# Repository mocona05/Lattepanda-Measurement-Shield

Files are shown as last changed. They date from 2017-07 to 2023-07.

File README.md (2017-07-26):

# Lattepanda-Measurement-Shield



Lattepanda Measurement Shield















https://tk-labs.blogspot.kr/2017/04/lattepanda-single-board-pc-mersument.html

https://youtu.be/Gao8uBBO_YQ?list=UUIPe5kHdhJTlKDBbaLlJSWA

https://tk-labs.blogspot.kr/2017/07/lattepanda-shield-4-wire-kelvin-circuit.html

https://youtu.be/S4dbSf8vbH0?list=UUIPe5kHdhJTlKDBbaLlJSWA

https://youtu.be/iEvZpjPi1Qs?list=UUIPe5kHdhJTlKDBbaLlJSWA

https://youtu.be/Fq8yy6oz41c?list=UUIPe5kHdhJTlKDBbaLlJSWA

https://tk-labs.blogspot.kr/2017/07/lattepanda-shiled-thermocouple-k-type.html

https://youtu.be/_V4gtJXVWEc

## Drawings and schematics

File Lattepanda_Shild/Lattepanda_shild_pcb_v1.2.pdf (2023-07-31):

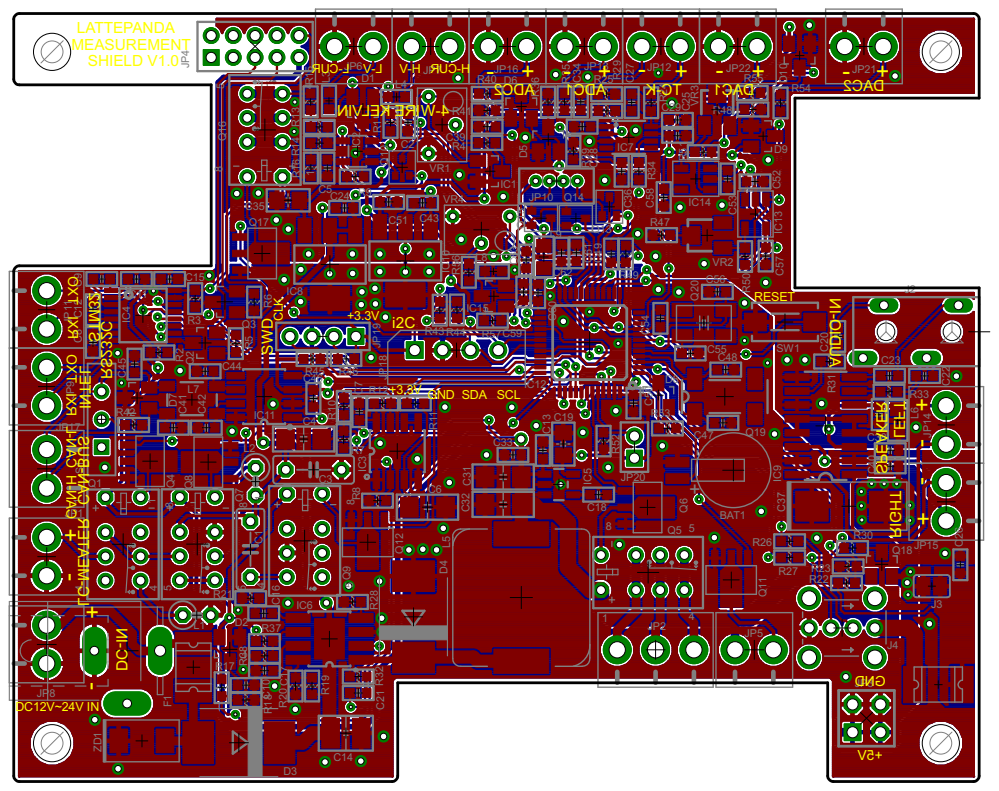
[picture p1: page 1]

T2XO RXI INTEL RXI TXO CAN-BUS

JP1 | C18 BAT1

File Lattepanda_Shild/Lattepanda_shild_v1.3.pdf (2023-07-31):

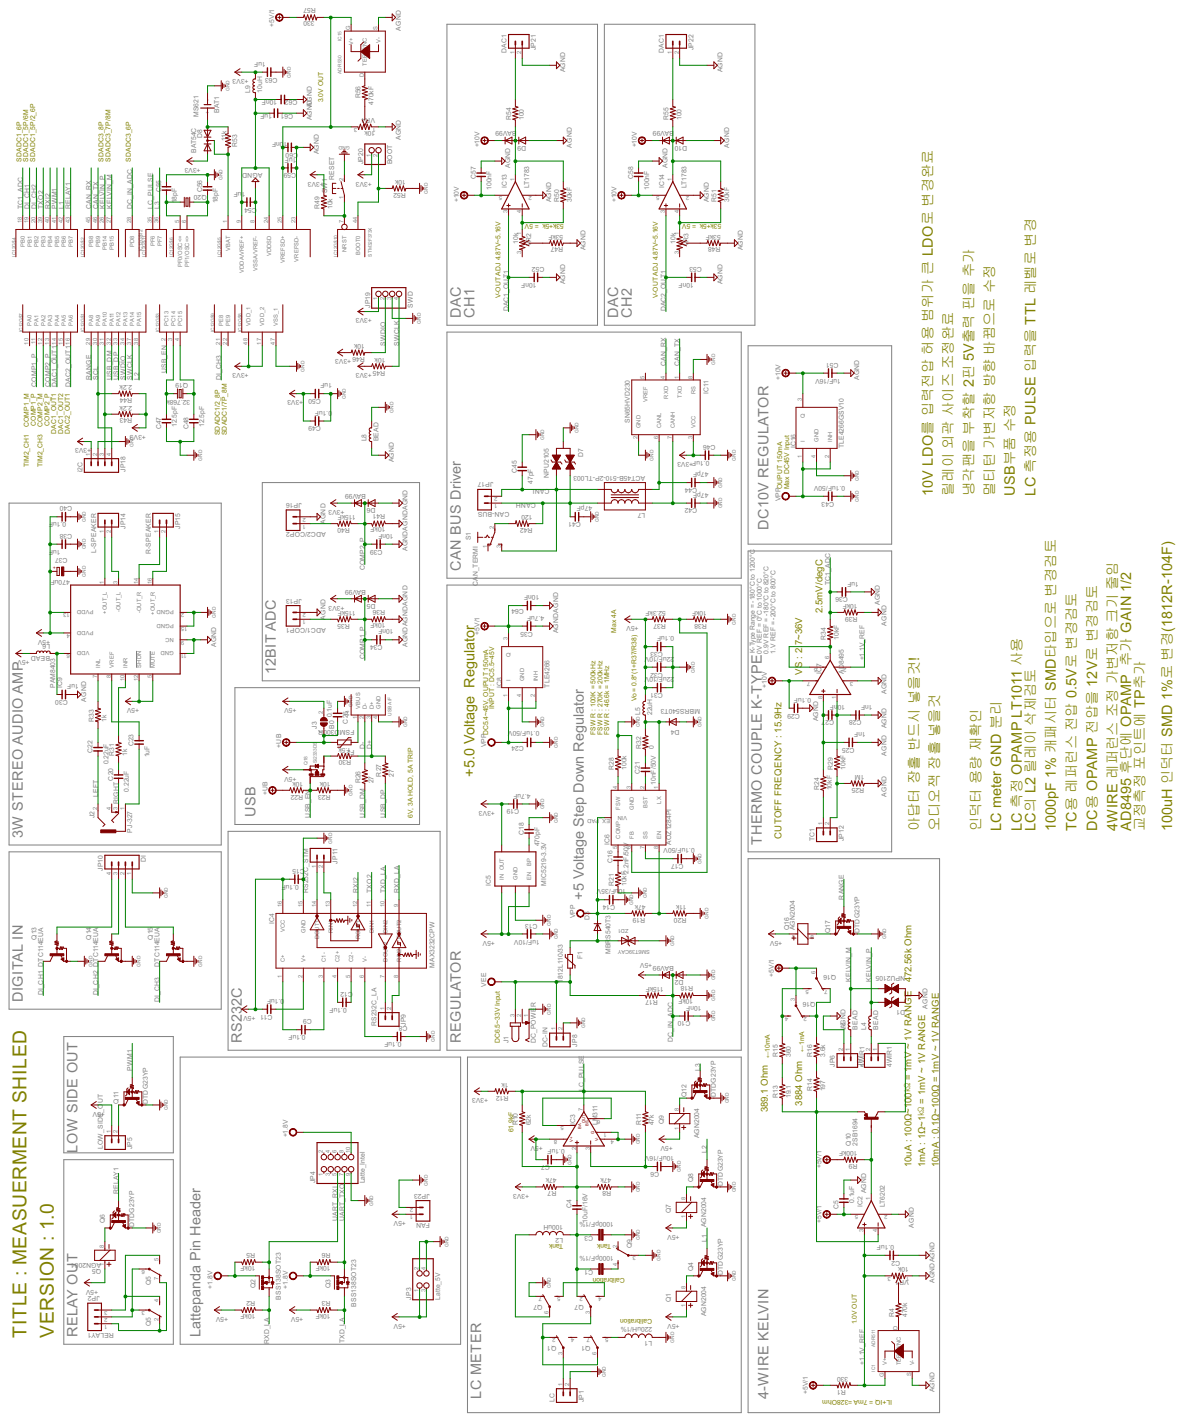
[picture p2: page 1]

1 VSSA/VREF- 8 VDDA/VREF+

LC 측정용 PULSE 입력을 TTL 레벨로 변경

10V LDO를 입력전압 허용 범위가

가 GAIN 1/2 교정측정 포인트에 TP추

TC용 레퍼런스 전압 0.5V로 변경검토

+5 Voltage Step Down Regulator

LC meter GND 분리

Lattepanda Pin Header USB

LOW SIDE OUT RELAY OUT DIGITAL IN

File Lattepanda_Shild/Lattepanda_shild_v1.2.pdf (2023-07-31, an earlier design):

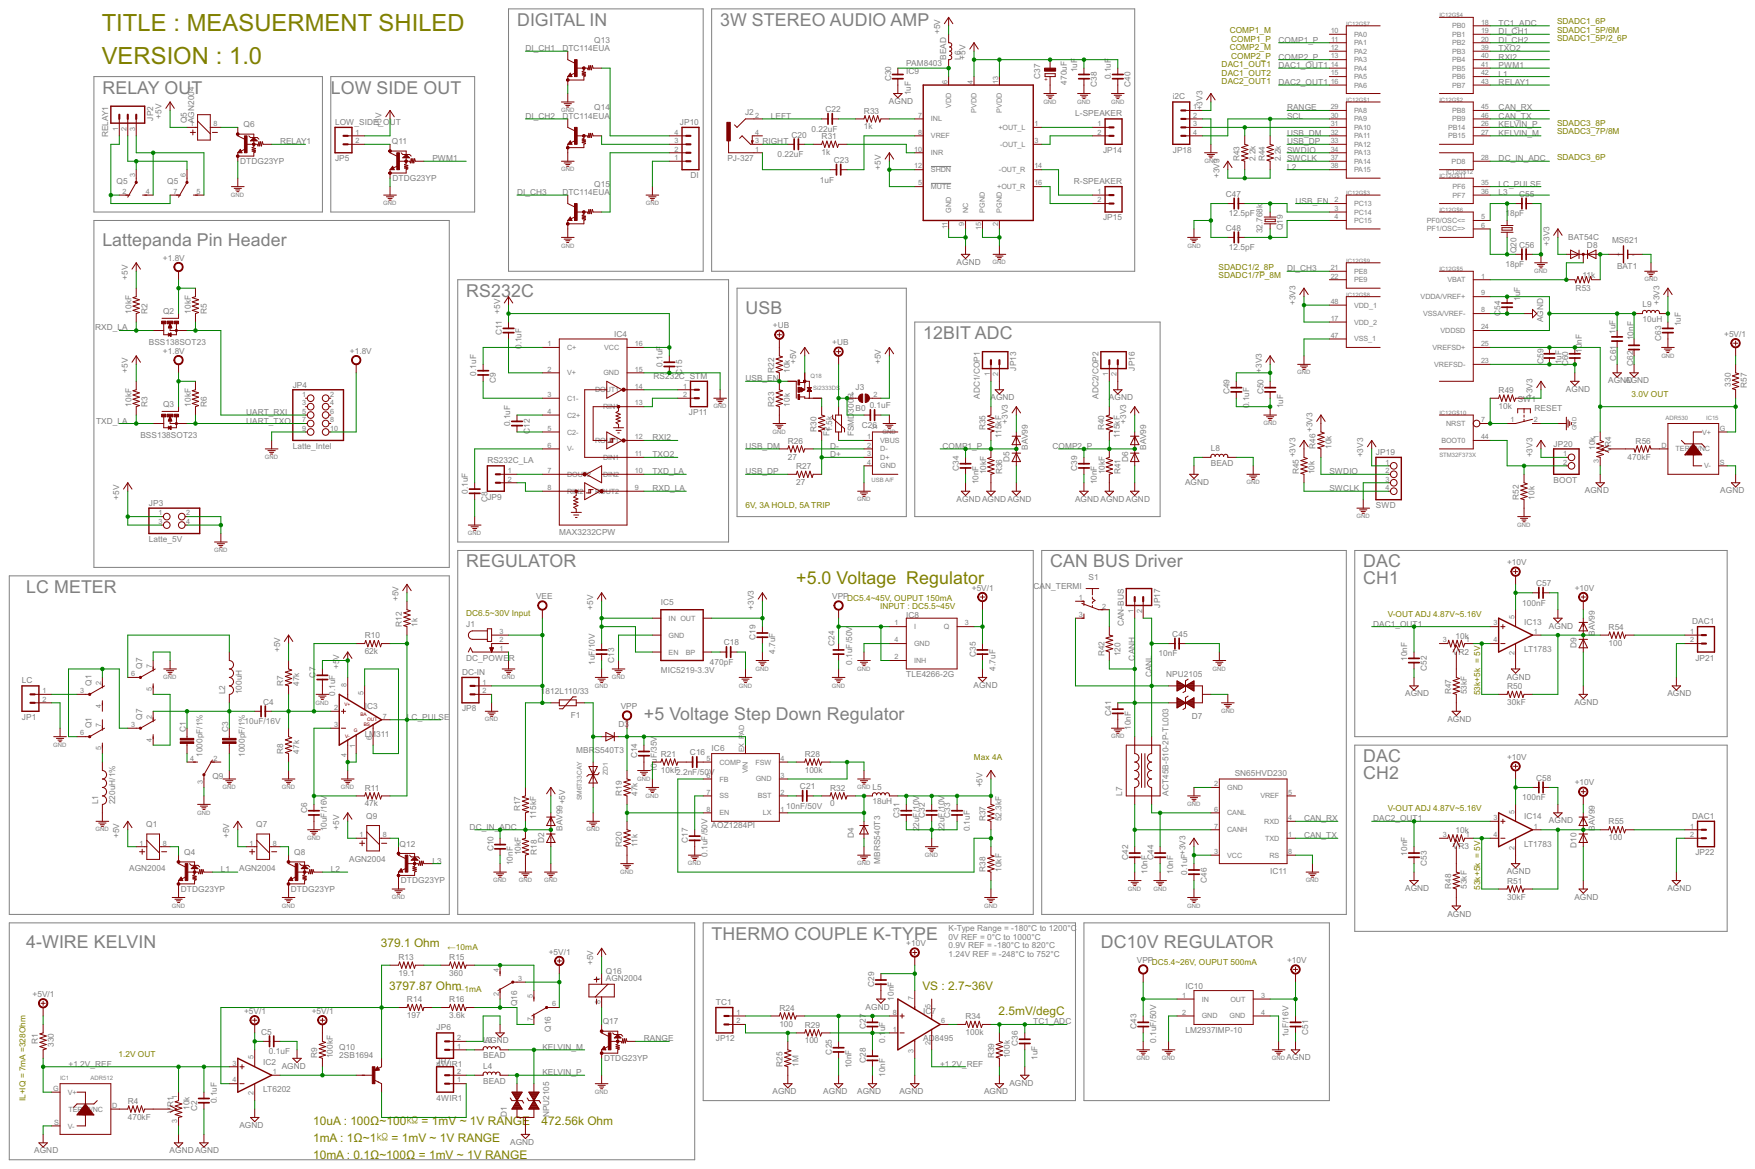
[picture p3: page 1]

+5 Voltage Step Down Regulator

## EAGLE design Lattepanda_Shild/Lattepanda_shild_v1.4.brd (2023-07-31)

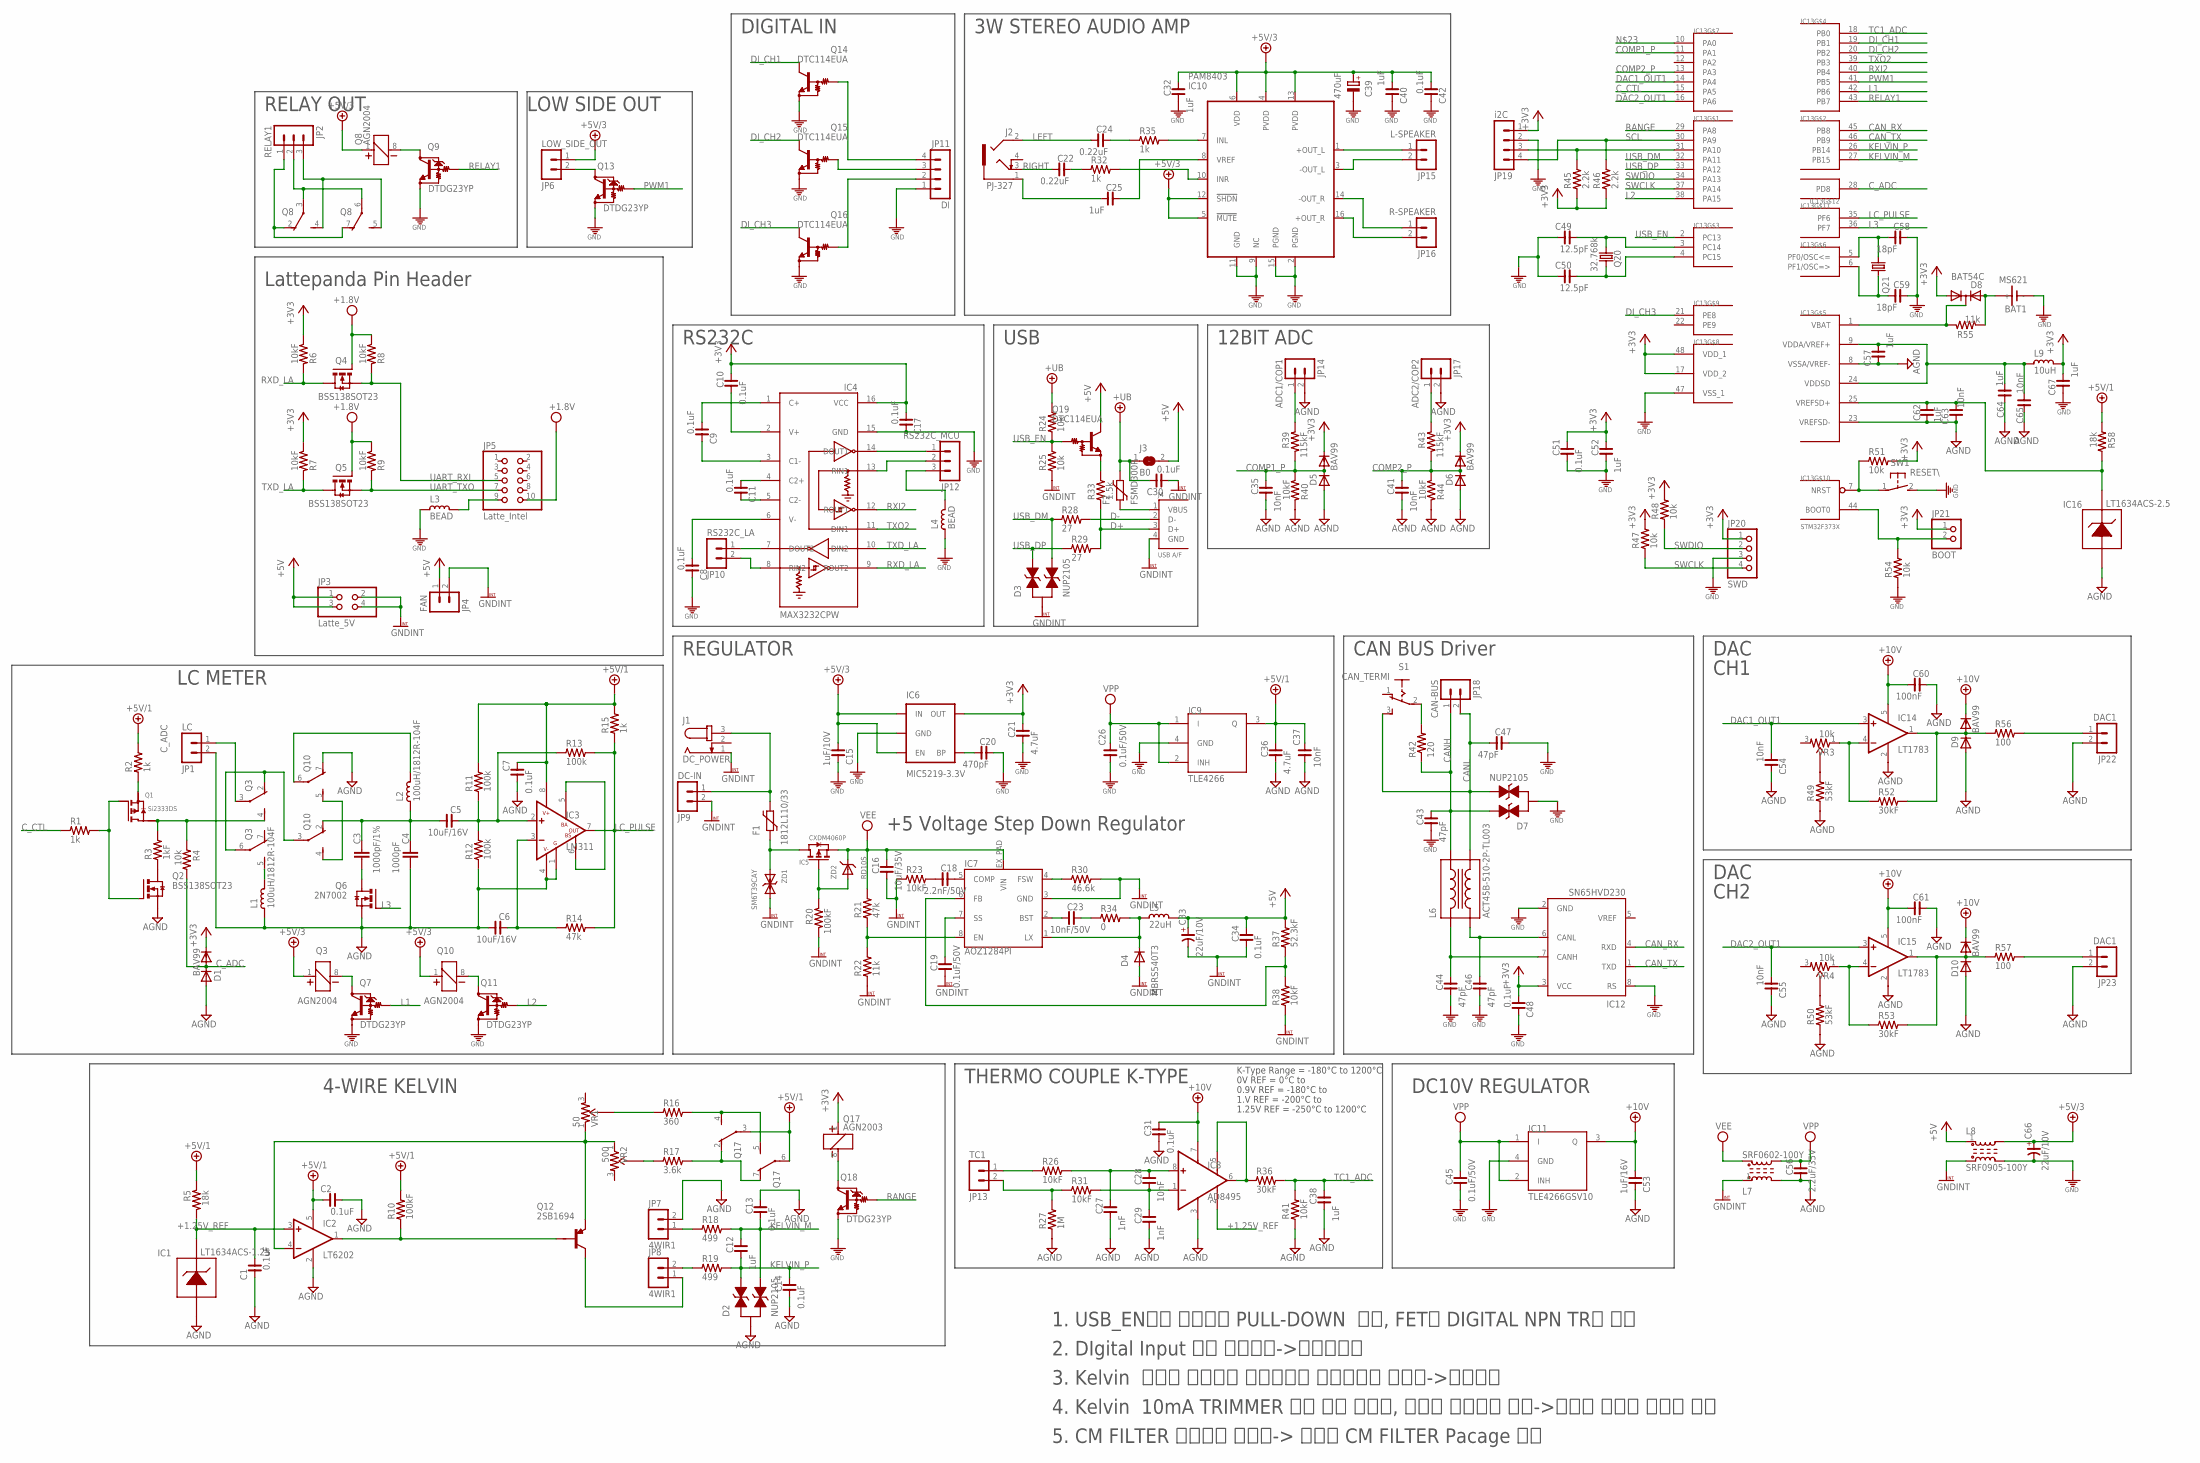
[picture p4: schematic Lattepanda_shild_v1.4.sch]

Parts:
BAT1: MS621
C1, C2, C7, C8, C9, C10, C11, C13, C14, C17, C30, C31, C34, C42, C48, C51: 0.1uF; C0603
C3: 1000pF/1%; C050-025X075
C4: 1000pF; C050-025X075
C5, C6: 10uF/16V; C3216
C12, C25, C32, C38, C40, C52, C57, C62, C64, C67: 1uF; C0603
C15: 1uF/10V; C0603
C16: 10uF/35V; C3225
C18: 2.2nF/50V; C0603
C19, C45: 0.1uF/50V; C0603
C20: 470pF; C0603
C21, C36: 4.7uF; C2012
C22, C24: 0.22uF; C0603
C23: 10nF/50V; C0603
C26: 0.1uF/50V; C1608-
C27, C29: 1nF; C0603
C28, C35, C41, C54, C55, C63, C65: 10nF; C0603
C33, C66: 22uF/10V; C3216-18/T
C37: 10nF; C1608-
C39: 470uF; D/7343-31W
C43, C44, C46, C47: 47pF; C0603
C49, C50: 12.5pF; C0603
C53: 1uF/16V; C0603
C56: 2.2uF/35V; C2012
C58, C59: 18pF; C0603
C60, C61: 100nF; C0603
D1, D5, D6, D9, D10: BAV99; SOT23
D2, D3, D7: NUP2105; SOT23
D4: MBRS540T3; SMC
D8: BAT54C; SOT23
F1: 1812L110/33; 1812L
F2: FSMD300R; 1812L
IC1: LT1634ACS-1.25; MS8
IC2: LT6202; SOT23-5L
IC3: LM311; SO8
IC4: MAX3232CPW; PW_R-PDSO-G16
IC5: CXDM4060P; SOT89
IC6: MIC5219-3.3V; SOT23-5
IC7: AOZ1284PI; S08-EP1
IC8: AD8495; MSOP8
IC9: TLE4266; SOT223-4
IC10: PAM8403; SOIC16N
IC11: TLE4266GSV10; SOT223-4
IC12: SN65HVD230; SO8
IC13: STM32F373X; TQFP48
IC14, IC15: LT1783; SOT23-5
IC16: LT1634ACS-2.5; MS8
J1: DC_POWER; SPC4077
J2: PJ-327; PJ-327-2
J3: B0; SJ
J4: USB A/F; USB_AF_SIDE
JP1: LC; ED350V-02P
JP2: RELAY1; ED350V-03P
JP3: Latte_5V; 2X02
JP4: FAN; MA02-1-MOL
JP5: Latte_Intel; 2X05M
JP6: LOW_SIDE_OUT; ED350V-02P
JP7, JP8: 4WIR1; ED350V-02P
JP9: DC-IN; ED350V-02P
JP10: RS232C_LA; ED350V-02P
JP11: DI; MOLEX5267-04
JP12: RS232C_MCU; ED350V-03P
JP13: TC1; ED350V-02P
JP14: ADC1/COP1; ED350V-02P
JP15: L-SPEAKER; ED350V-02P
JP16: R-SPEAKER; ED350V-02P
JP17: ADC2/COP2; ED350V-02P
JP18: CAN-BUS; ED350V-02P
JP19: i2C; MOLEX5267-04
JP20: SWD; 1X04M
JP21: BOOT; 1X02M
JP22, JP23: DAC1; ED350V-02P
L1, L2: 100uH/1812R-104F; L1210
L3, L4: BEAD; L0603
L5: 22uH; SHP1260P-F
L6: ACT45B-510-2P-TL003; ACT45B
L7: SRF0602-100Y; SRF0602
L8: SRF0905-100Y; SRF0905
L9: 10uH; L0805
Q1: Si2333DS; SOT23
Q2, Q4, Q5: BSS138SOT23; SOT23
Q3, Q8, Q10: AGN2004; ANG200X
Q6: 2N7002; SOT23
Q7, Q9, Q11, Q13, Q18: DTDG23YP; MPT3
Q12: 2SB1694; SOT323
Q14, Q15, Q16, Q19: DTC114EUA; SC59-BEC
Q17: AGN2003; ANG200X
Q20: 32.768k; MC-306
Q21: 8MHz; SMD5032
R1, R2, R15, R32, R35: 1k; R0603
R3: 1kF; R0603
R4, R24, R25, R47, R48, R51, R54: 10k; R0603
R5, R58: 18k; R0603
R6, R7, R8, R9, R23, R26, R31, R38, R40, R41, R44: 10kF; R0603
R10, R20: 100kF; R0603
R11, R12, R13: 100k; R0603
R14, R21: 47k; R0603
R16: 360; R0603
R17: 3.6k; R0603
R18, R19: 499; R0603
R22, R55: 11k; R0603
R27: 1M; R0603
R28, R29: 27; R0603
R30: 46.6k; R0603
R33: 1.5k; R0603
R34: 0; R0603
R36, R52, R53: 30kF; R0603
R37: 52.3kF; R0603
R39, R43: 115kF; R0603
R42: 120; R0603@1
R45, R46: 2.2k; R0603
R49, R50: 53kF; R0603
R56, R57: 100; R0603
S1: CAN_TERMI; 255SB
SW1: RESET\; DTSM-3
VR1: 50; R-TRIMMER-3313J
VR2: 500; R-TRIMMER-3313J
VR3, VR4: 10k; R-TRIMMER-3313J
ZD1: SM6T39CAY; SMB
ZD2: RD10S; DSMM

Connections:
+1.25V_REF: C1.2, IC1.6 (VOUT), IC2.3 (+IN), IC8.2 (REF), R5.2
+3V3: C10.1, C17.2, C21.1, C48.2, C51.1, C52.1, C67.2, D1.S (C), D5.S (C), D6.S (C), D8.G (1), IC4.16 (VCC), IC6.5 (OUT), IC12.3 (VCC), IC13.17 (VDD_2), IC13.48 (VDD_1), JP19.1, JP20.1, JP21.1, L9.1, Q17.1, R6.2, R7.2, R45.1, R46.1, R47.2, R48.2, R51.2
+5V: C33.+, C34.1, J3.2, JP3.1, JP3.3, JP4.1, L5.1, L8.1, Q19.3 (OUT), R37.2
+5V/1: C2.1, C7.1, C36.1, C37.2, IC2.5 (V+), IC3.8 (V+), IC9.3 (Q), Q17.3, Q17.6, R2.2, R5.1, R10.2, R11.2, R15.2, R58.1
+5V/3: C15.2, C32.1, C39.+, C40.2, C42.2, C66.+, IC6.1 (IN), IC6.3 (EN), IC10.4 (PVDD), IC10.5 (!MUTE), IC10.6 (VDD), IC10.12 (!SHDN), IC10.13 (PVDD), JP6.1, L8.2, Q3.1, Q8.1, Q10.1
+10V: C31.1, C53.2, C60.2, C61.2, D9.S (C), D10.S (C), IC8.7 (V+), IC11.3 (Q), IC14.5 (V+), IC15.5 (V+)
+UB: C30.1, F2.P$2 (2), J3.1, R24.2
AGND: C1.1, C2.2, C4.2, C6.2, C7.2, C13.1, C14.2, C27.2, C29.2, C31.2, C35.2, C36.2, C37.1, C38.2, C41.2, C53.1, C54.1, C55.1, C56.2, C57.1, C60.1, C61.1, C62.2, C63.1, C64.1, C65.1, D1.G (A), D2.D (PIN3), D5.G (A), D6.G (A), D9.G (A), D10.G (A), IC1.4 (GND), IC2.2 (V-), IC3.1 (G), IC3.4 (V-), IC8.3 (V-), IC13.8 (VSSA/VREF-), IC13.23 (VREFSD-), IC14.2 (V-), IC15.2 (V-), IC16.4 (GND), JP1.2, JP7.2, JP14.2, JP17.2, JP22.2, JP23.2, L1.2, L7.2, Q2.S, Q6.S, Q10.7 (O), R12.1, R27.1, R40.1, R41.1, R44.1, R49.1, R50.1
BOOT1: IC13.44 (BOOT0), JP21.2, R54.2
CANH: C43.1, D7.G (PIN1), JP18.1, L6.4, R42.1
CANL: C47.2, D7.S (PIN2), JP18.2, L6.3, S1.3 (S)
CAN_RX: IC12.4 (RXD), IC13.45 (PB8)
CAN_TX: IC12.1 (TXD), IC13.46 (PB9)
COMP1_P: C35.1, D5.D (AC), IC13.11 (PA1), R39.2, R40.2
COMP2_P: C41.1, D6.D (AC), IC13.13 (PA3), R43.2, R44.2
C_ADC: D1.D (AC), IC13.28 (PD8), R4.2
C_CTL: IC13.15 (PA5), R1.1
D+: J4.3 (D+), R29.2, R33.1
D-: J4.2 (D-), R28.2
DAC1_OUT1: C54.2, IC13.14 (PA4), IC14.3 (+IN)
DAC2_OUT1: C55.2, IC13.16 (PA6), IC15.3 (+IN)
DC-IN: F1.P$1 (1), IC5.2 (D), IC5.2@1 (D), ZD1.A
DI_CH1: IC13.19 (PB1), Q14.3 (OUT)
DI_CH2: IC13.20 (PB2), Q15.3 (OUT)
DI_CH3: IC13.21 (PE8), Q16.3 (OUT)
GND: BAT1.-, C8.1, C15.1, C17.1, C20.1, C21.2, C26.1, C32.2, C39.-, C40.1, C42.1, C43.2, C44.2, C45.2, C46.2, C47.1, C48.1, C49.1, C50.1, C51.2, C52.2, C58.1, C59.1, C66.-, C67.1, D7.D (PIN3), IC4.15 (GND), IC6.2 (GND), IC9.4 (GND), IC10.2 (PGND), IC10.9 (NC), IC10.11 (GND), IC10.15 (PGND), IC11.4 (GND), IC12.2 (GND), IC12.8 (RS), IC13.47 (VSS_1), JP11.1, JP19.2, JP20.3, L3.2, L4.2, L8.3, Q7.EMITTER (GND), Q9.EMITTER (GND), Q11.EMITTER (GND), Q13.EMITTER (GND), Q14.1 (GND), Q15.1 (GND), Q16.1 (GND), Q18.EMITTER (GND), R54.1, SW1.2
GNDINT: C16.2, C19.2, C30.2, C33.-, C34.2, D3.D (PIN3), D4.A, IC7.3 (GND), J1.1, J4.4 (GND), JP3.2, JP3.4, JP4.2, JP9.2, L7.1, L8.4, R20.2, R22.1, R23.1, R25.1, R30.2, R38.1, ZD1.C (K)
KELVIN_M: C12.1, C13.2, D2.S (PIN2), IC13.27 (PB15), R18.2
KELVIN_P: C12.2, C14.1, D2.G (PIN1), IC13.26 (PB14), R19.2
L1: IC13.42 (PB6), Q7.BASE (IN)
L2: IC13.38 (PA15), Q11.BASE (IN)
L3: IC13.36 (PF7), Q6.G
LC_PULSE: IC3.7 (OUT), IC13.35 (PF6), R13.2, R14.2, R15.1
LEFT: C24.2, J2.2
unnamed: JP6.2, Q13.COLLECTOR (OUT)
unnamed: JP12.3, L4.1
unnamed: IC7.6 (FB), R37.1, R38.2
unnamed: C23.2, IC7.2 (BST)
unnamed: C46.1, IC12.6 (CANL), L6.2
unnamed: C44.1, IC12.7 (CANH), L6.1
unnamed: R17.1, VR2.2
unnamed: C23.1, R34.1
unnamed: D4.C, IC7.1 (LX), L5.2, R34.2
unnamed: C18.1, IC7.5 (COMP)
unnamed: C18.2, R23.2
unnamed: R42.2, S1.2
unnamed: R50.2, VR4.2
unnamed: C11.1, IC4.5 (C2-)
unnamed: C11.2, IC4.4 (C2+)
unnamed: C10.2, IC4.2 (V+)
unnamed: IC15.4 (-IN), R53.1, VR4.1
unnamed: D10.D (AC), IC15.1 (OUT), R53.2, R57.1
unnamed: IC7.8 (EN), R21.1, R22.2
unnamed: JP7.1, R18.1
unnamed: IC7.4 (FSW), R30.1
unnamed: JP8.2, R19.1
unnamed: C19.1, IC7.7 (SS)
unnamed: D8.D (3), IC13.1 (VBAT), R55.1
unnamed: C8.2, IC4.6 (V-)
unnamed: C9.2, IC4.1 (C+)
unnamed: IC4.8 (RIN2), JP10.2
unnamed: C9.1, IC4.3 (C1-)
unnamed: IC2.1 (OUT), Q12.2 (B), R10.1
unnamed: Q8.8 (2), Q9.COLLECTOR (OUT)
unnamed: IC4.7 (DOUT2), JP10.1
unnamed: JP5.9, L3.1
unnamed: IC13.7 (NRST), R51.1, SW1.1
unnamed: C59.2, IC13.6 (PF1/OSC=>), Q21.3 (2)
unnamed: IC4.13 (RIN1), JP12.2
unnamed: IC3.5 (BA), IC3.6 (BS)
unnamed: C57.2, C64.2, C65.2, IC13.9 (VDDA/VREF+), IC13.24 (VDDSD), L9.2
unnamed: C6.1, IC3.3 (-IN), R14.1
unnamed: IC4.14 (DOUT1), JP12.1
unnamed: C28.2, C29.1, IC8.1 (-IN), R31.2
unnamed: C27.1, C28.1, IC8.8 (+IN), R26.2
unnamed: IC10.7 (INL), R35.2
unnamed: IC10.1 (+OUT_L), JP15.1
unnamed: JP13.2, R27.2, R31.1
unnamed: JP13.1, R26.1
unnamed: IC8.5 (SENS), IC8.6 (OUT), R36.1
unnamed: C5.1, IC3.2 (+IN), R11.1, R12.2, R13.1
unnamed: JP8.1, Q12.3 (C)
unnamed: JP14.1, R39.1
unnamed: JP17.1, R43.1
unnamed: IC10.3 (-OUT_L), JP15.2
unnamed: IC10.14 (-OUT_R), JP16.1
unnamed: IC10.16 (+OUT_R), JP16.2
unnamed: IC10.10 (INR), R32.2
unnamed: C25.1, IC10.8 (VREF)
unnamed: C25.2, J2.1
unnamed: C24.1, R35.1
unnamed: F2.P$1 (1), J4.1 (VBUS)
unnamed: JP22.1, R56.2
unnamed: Q1.S (SOURCE), R2.1
unnamed: C20.2, IC6.4 (BP)
unnamed: Q2.D, R3.1
unnamed: R16.1, VR1.2
unnamed: C22.1, R32.1
unnamed: Q17.8 (2), Q18.COLLECTOR (OUT)
unnamed: Q17.4 (S), Q17.5 (S), R16.2
unnamed: C62.1, C63.2, IC13.25 (VREFSD+), IC16.6 (VOUT), R58.2
unnamed: L1.1, Q3.5 (S)
unnamed: IC2.4 (-IN), Q12.1 (E), VR1.1, VR2.1
unnamed: IC14.4 (-IN), R52.1, VR3.1
unnamed: Q17.2 (O), Q17.7 (O), R17.2
unnamed: Q10.4 (S), Q10.5 (S)
unnamed: C3.1, C4.1, C5.2, L2.2, Q10.2 (O)
unnamed: Q1.G (GATE), Q2.G, R1.2
unnamed: Q10.8 (2), Q11.COLLECTOR (OUT)
unnamed: Q3.2 (O), Q3.6, Q10.3
unnamed: C3.2, Q6.D
unnamed: L2.1, Q10.6
unnamed: Q3.8 (2), Q7.COLLECTOR (OUT)
unnamed: Q19.1 (GND), R33.2
unnamed: Q1.D (DRAIN), Q3.4 (S), R3.2, R4.1
unnamed: JP1.1, Q3.3
unnamed: D9.D (AC), IC14.1 (OUT), R52.2, R56.1
unnamed: R49.2, VR3.2
unnamed: JP2.2, Q8.3, Q8.6
unnamed: C58.2, IC13.5 (PF0/OSC<=), Q21.1
unnamed: JP2.1, Q8.2 (O), Q8.7 (O)
unnamed: JP2.3, Q8.4 (S), Q8.5 (S)
unnamed: JP23.1, R57.2
unnamed: IC13.31 (PA10), JP19.3, R45.2
unnamed: BAT1.+, D8.S (2), R55.2
unnamed: JP11.2, Q16.2 (IN)
unnamed: JP11.3, Q15.2 (IN)
unnamed: C49.2, IC13.3 (PC14), Q20.1
unnamed: C50.2, IC13.4 (PC15), Q20.4 (2)
unnamed: JP11.4, Q14.2 (IN)
unnamed: IC5.3 (G), R20.1, ZD2.A
unnamed: F1.P$2 (2), J1.3, JP9.1
PWM1: IC13.41 (PB5), Q13.BASE (IN)
RANGE: IC13.29 (PA8), Q18.BASE (IN)
RELAY1: IC13.43 (PB7), Q9.BASE (IN)
RIGHT: C22.2, J2.3
RXD_LA: IC4.9 (ROUT2), Q4.D, R6.1
RXI2: IC4.12 (ROUT1), IC13.40 (PB4)
SCL: IC13.30 (PA9), JP19.4, R46.2
SWCLK: IC13.37 (PA14), JP20.4, R47.1
SWDIO: IC13.34 (PA13), JP20.2, R48.1
TC1_ADC: C38.1, IC13.18 (PB0), R36.2, R41.2
TXD_LA: IC4.10 (DIN2), Q5.D, R7.1
TXO2: IC4.11 (DIN1), IC13.39 (PB3)
UART_RXI: JP5.5, Q4.S, R8.1
UART_TXO: JP5.7, Q5.S, R9.1
USB_DM: D3.S (PIN2), IC13.32 (PA11), R28.1
USB_DP: D3.G (PIN1), IC13.33 (PA12), R29.1
USB_EN: IC13.2 (PC13), Q19.2 (IN), R24.1, R25.2
VDD: JP5.10, Q4.G, Q5.G, R8.2, R9.2
VEE: C16.1, IC5.1 (S), IC7.EX_PAD (VIN), L7.4, R21.2, ZD2.C
VPP: C26.2, C45.1, C56.1, IC9.1 (I), IC9.2 (INH), IC11.1 (I), IC11.2 (INH), L7.3

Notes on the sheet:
+5 Voltage Step Down Regulator
3W STEREO AUDIO AMP
Lattepanda Pin Header
USB
CAN BUS Driver
4-WIRE KELVIN
K-Type Range = -180°C to 1200°C
1.V REF = -200°C to
0.9V REF = -180°C to
0V REF = 0°C to
LC METER
DAC
THERMO COUPLE K-TYPE
RS232C
REGULATOR
DC10V REGULATOR
12BIT ADC
CH1
CH2
LOW SIDE OUT
RELAY OUT
DIGITAL IN
1.25V REF = -250°C to 1200°C
1. USB_EN회로 수정필요 PULL-DOWN 삭제, FET를 DIGITAL NPN TR로 변경
2. DIgital Input 회로 수정필요->큰문제없음
3. Kelvin 회로의 전류조정 가변저항이 회전방향이 반대임->변경완료
4. Kelvin 10mA TRIMMER 저항 용량 재검토, 멀티턴 저항으로 검토->공간적 제약이 문제로 포기
5. CM FILTER 인덕턴스 재검토-> 전원부 CM FILTER Pacage 교체

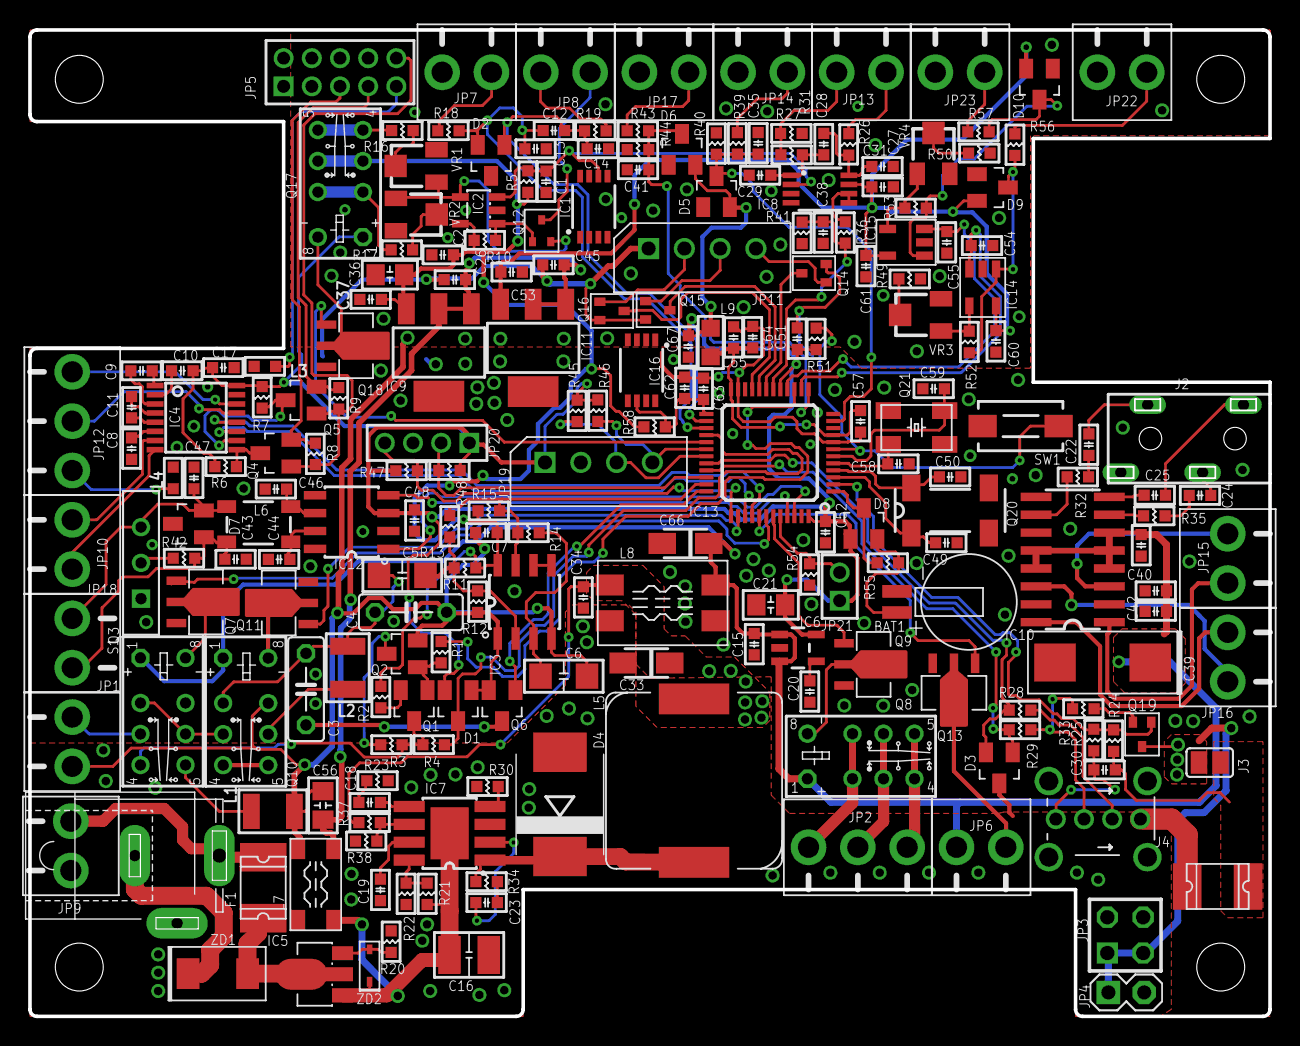
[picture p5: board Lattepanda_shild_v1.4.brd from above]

Board: 2 copper layers, 88.0 x 70.0 mm, 219 parts (0 on the bottom side), 152 nets.

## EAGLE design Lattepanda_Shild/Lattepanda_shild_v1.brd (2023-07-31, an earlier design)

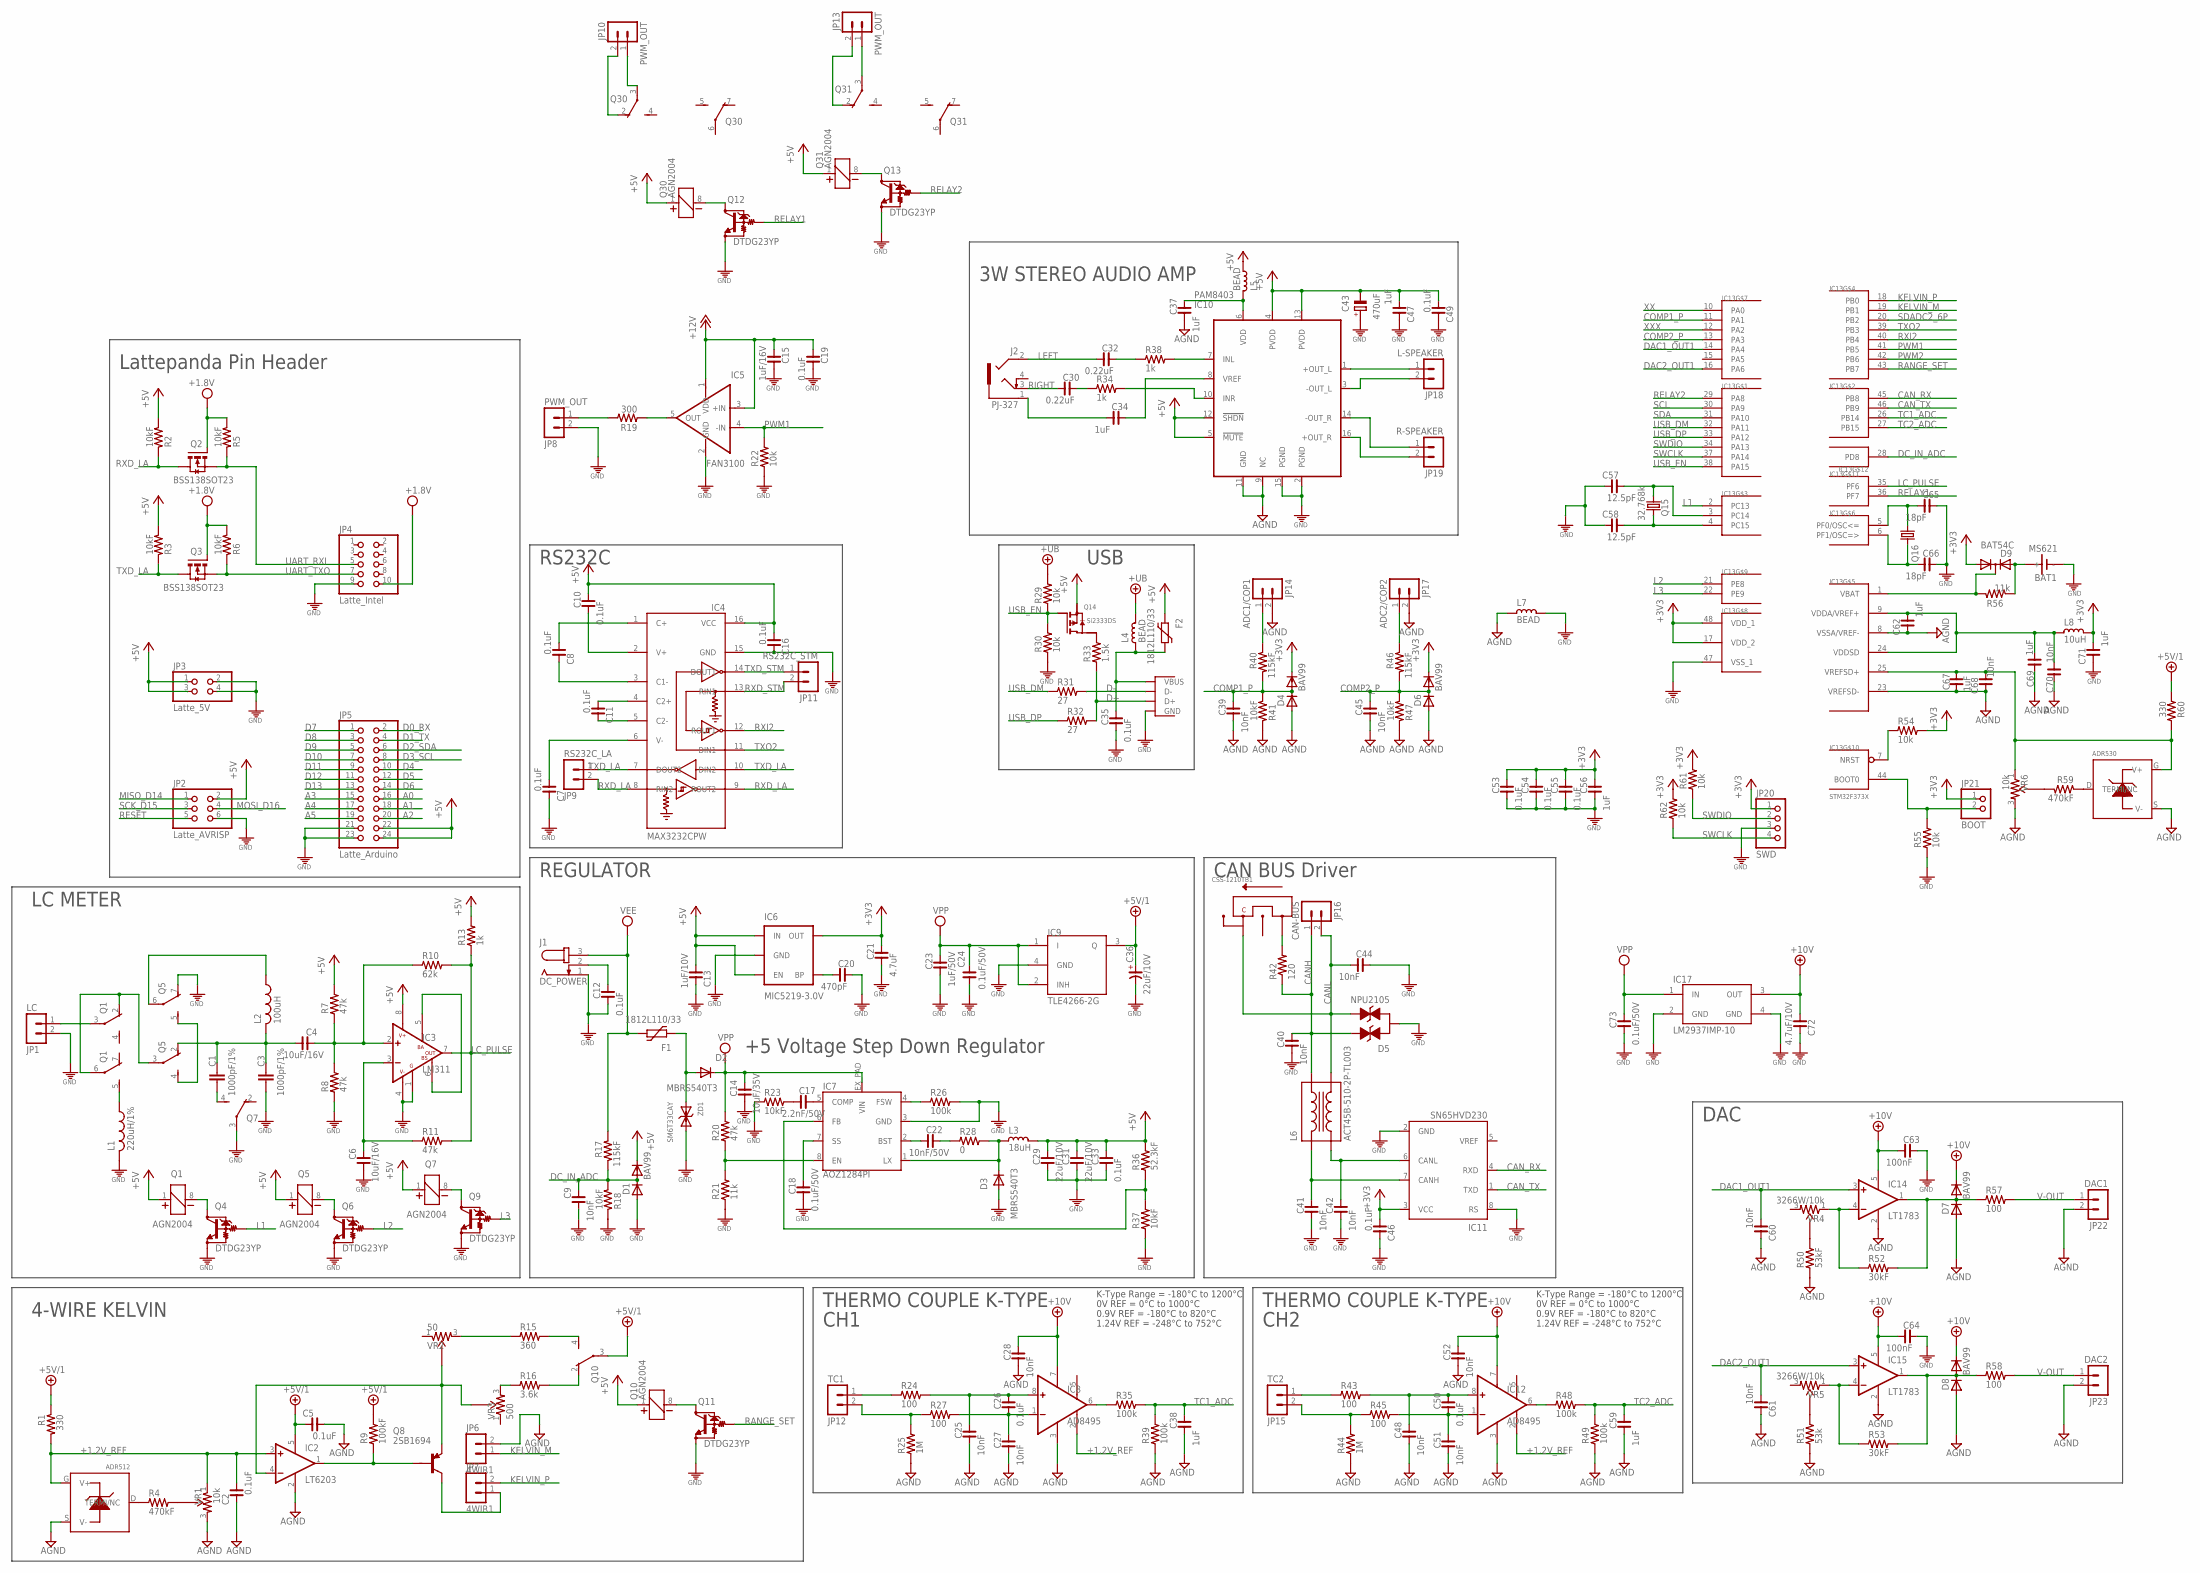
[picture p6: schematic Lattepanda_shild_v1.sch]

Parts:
BAT1: MS621
C1, C3: 1000pF/1%; C050-025X075
C2, C5, C7, C8, C10, C11, C12, C16, C19, C26, C33, C35, C46, C49, C50, C53, C54, C55: 0.1uF; C0603
C4, C6: 10uF/16V; C3216
C9, C25, C27, C28, C39, C40, C41, C42, C44, C45, C48, C51, C52, C60, C61, C68, C70: 10nF; C0603
C13: 1uF/10V; C0603
C14: 10uF/35V; C3225
C15: 1uF/16V; C0805
C17: 2.2nF/50V; C0603
C18, C73: 0.1uF/50V; C0603
C20: 470pF; C0603
C21: 4.7uF; C2012
C22: 10nF/50V; C0603
C23: 1uF/50V; C2012
C24: 0.1uF/50V; C1608-
C29, C31: 22uF/10V; C3216
C30, C32: 0.22uF; C0603
C34, C37, C38, C47, C56, C59, C62, C67, C69, C71: 1uF; C0603
C36: 22uF/10V; C3528-21/T
C43: 470uF; D/7343-31W
C57, C58: 12.5pF; C0603
C63, C64: 100nF; C0603
C65, C66: 18pF; C0603
C72: 4.7uF/10V; C2012
D1, D4, D6, D7, D8: BAV99; SOT23
D2, D3: MBRS540T3; SMC
D5: NPU2105; SOT23
D9: BAT54C; SOT23
F1, F2: 1812L110/33; 1812L
IC1: ADR512; SOT23
IC2: LT6203; SOT23-5L
IC3: LM311; SO8
IC4: MAX3232CPW; PW_R-PDSO-G16
IC5: FAN3100; SOT23-5L_FAN3100
IC6: MIC5219-3.0V; SOT23-5
IC7: AOZ1284PI; S08-EP1
IC8, IC12: AD8495; MSOP8
IC9: TLE4266-2G; SOT223-4
IC10: PAM8403; SOIC16N
IC11: SN65HVD230; SO8
IC13: STM32F373X; TQFP48
IC14, IC15: LT1783; SOT23-5
IC16: ADR530; SOT23
IC17: LM2937IMP-10; SOT223
J1: DC_POWER; SPC4077
J2: PJ-327; PJ-327-2
JP1: LC; ED350V-02P
JP2: Latte_AVRISP; 2X03
JP3: Latte_5V; 2X02
JP4: Latte_Intel; 2X05M
JP5: Latte_Arduino; 2X12_SMD
JP6, JP7: 4WIR1; ED350V-02P
JP8, JP10, JP13: PWM_OUT; ED350V-02P
JP9: RS232C_LA; ED350V-02P
JP11: RS232C_STM; ED350V-02P
JP12: TC1; ED350V-02P
JP14: ADC1/COP1; ED350V-02P
JP15: TC2; ED350V-02P
JP16: CAN-BUS; ED350V-02P
JP17: ADC2/COP2; ED350V-02P
JP18: L-SPEAKER; ED350V-02P
JP19: R-SPEAKER; ED350V-02P
JP20: SWD; 1X04M
JP21: BOOT; 1X02M
JP22: DAC1; ED350V-02P
JP23: DAC2; ED350V-02P
L1: 220uH/1%; 0207/2V
L2: 100uH; 0207/2V
L3: 18uH; SHP1260P-F
L4, L5: BEAD; L0805
L6: ACT45B-510-2P-TL003; ACT45B
L7: BEAD; L0603
L8: 10uH; L0805
Q1, Q5, Q7, Q10, Q30, Q31: AGN2004; ANG200X
Q2, Q3: BSS138SOT23; SOT23
Q4, Q6, Q9, Q11, Q12, Q13: DTDG23YP; MPT3
Q8: 2SB1694; SOT323
Q14: Si2333DS; SOT23
Q15: 32.768k; MC-306
Q16: 8MHz; SMD5032
R1, R60: 330; R0603
R2, R3, R5, R6, R18, R23, R37, R41, R47: 10kF; R0603
R4, R59: 470kF; R0603
R7, R8, R11, R20: 47k; R0603
R9: 100kF; R0603
R10: 62k; R0603
R13, R34, R38: 1k; R0603
R15: 360; R0603
R16: 3.6k; R0603
R17, R40, R46: 115kF; R0603
R19: 300; R0603
R21, R56: 11k; R0603
R22, R29, R30, R54, R55, R61, R62: 10k; R0603
R24, R27, R43, R45, R57, R58: 100; R0603
R25, R44: 1M; R0603
R26, R35, R39, R48, R49: 100k; R0603
R28: 0; R0603
R31, R32: 27; R0603
R33: 1.5k; R0603
R36: 52.3kF; R0603
R42: 120; R0603@1
R50: 53kF; R0603
R51: 53k; R0603
R52, R53: 30kF; R0603
SW1: CSS-1210TB1; CSS-1210TB
VR1, VR6: 10k; 3266W
VR2: 50; 3266W
VR3: 500; 3266W
VR4, VR5: 3266W/10k; 3266W
X1: USB-A-H
ZD1: SM6T33CAY; SMB

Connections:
+1.2V_REF: C2.2, IC1.G (V+), IC2.3 (+IN), IC8.2 (REF), IC12.2 (REF), R1.2, VR1.1
+3V3: C21.1, C46.2, C53.1, C54.1, C55.1, C56.1, C71.2, D4.S (C), D6.S (C), D9.G (1), IC6.5 (OUT), IC11.3 (VCC), IC13.17 (VDD_2), IC13.48 (VDD_1), JP20.1, JP21.1, L8.1, R54.2, R61.2, R62.2
+5V: C10.1, C13.2, C16.2, C29.1, C31.1, C33.1, C43.-, C47.2, C49.2, D1.S (C), F2.P$1 (1), IC3.8 (V+), IC4.16 (VCC), IC6.1 (IN), IC6.3 (EN), IC10.4 (PVDD), IC10.5 (!MUTE), IC10.12 (!SHDN), IC10.13 (PVDD), JP2.2, JP3.1, JP3.3, JP5.22, JP5.24, L3.1, L5.1, Q1.1, Q5.1, Q7.1, Q10.1, Q14.S (SOURCE), Q30.1, Q31.1, R2.2, R3.2, R7.2, R13.2, R36.2
+5V/1: C5.1, C36.+, IC2.5 (V+), IC9.3 (Q), Q10.3, R1.1, R9.2, R60.1
+10V: C28.1, C52.1, C63.2, C64.2, C72.2, D7.S (C), D8.S (C), IC8.7 (V+), IC12.7 (V+), IC14.5 (V+), IC15.5 (V+), IC17.3 (OUT)
+12V: C15.1, C19.1, IC5.1 (VDD), IC5.3 (+IN)
+UB: L4.1, R29.2
A0: JP5.16
A1: JP5.18
A2: JP5.20
A3: JP5.15
A4: JP5.17
A5: JP5.19
AGND: C2.1, C5.2, C25.2, C27.2, C28.2, C37.2, C38.2, C39.2, C45.2, C48.2, C51.2, C52.2, C59.2, C60.1, C61.1, C62.1, C67.2, C68.1, C69.1, C70.1, D4.G (A), D6.G (A), D7.G (A), D8.G (A), IC1.S (V-), IC2.2 (V-), IC8.3 (V-), IC10.9 (NC), IC10.11 (GND), IC12.3 (V-), IC13.8 (VSSA/VREF-), IC13.23 (VREFSD-), IC14.2 (V-), IC15.2 (V-), IC16.S (V-), JP6.2, JP14.2, JP17.2, JP22.2, JP23.2, L7.2, R25.1, R39.1, R41.1, R44.1, R47.1, R49.1, R50.1, R51.1, VR1.3, VR6.3
BOOT1: IC13.44 (BOOT0), JP21.2, R55.2
CANH: C40.1, D5.G (PIN1), JP16.1, L6.4, R42.1
CANL: C44.2, D5.S (PIN2), JP16.2, L6.3, SW1.3
CAN_RX: IC11.4 (RXD), IC13.45 (PB8)
CAN_TX: IC11.1 (TXD), IC13.46 (PB9)
COMP1_P: C39.1, D4.D (AC), IC13.11 (PA1), R40.2, R41.2
COMP2_P: C45.1, D6.D (AC), IC13.13 (PA3), R46.2, R47.2
D0_RX: JP5.2
D1_TX: JP5.4
D2_SDA: JP5.6
D3_SCL: JP5.8
D4: JP5.10
D5: JP5.12
D6: JP5.14
D7: JP5.1
D8: JP5.3
D9: JP5.5
D10: JP5.7
D11: JP5.9
D12: JP5.11
D13: JP5.13
D+: R32.2, R33.1, X1.D+
D-: R31.2, X1.D-
DAC1_OUT1: C60.2, IC13.14 (PA4), IC14.3 (+IN)
DAC2_OUT1: C61.2, IC13.16 (PA6), IC15.3 (+IN)
DC-IN: D2.A, F1.P$1 (1), ZD1.A
DC_IN_ADC: C9.1, D1.D (AC), IC13.28 (PD8), R17.2, R18.2
GND: BAT1.-, C3.2, C6.2, C7.1, C9.2, C12.2, C13.1, C14.2, C15.2, C16.1, C18.2, C19.2, C20.1, C21.2, C23.2, C24.1, C29.2, C31.2, C33.2, C35.2, C36.-, C40.2, C41.2, C42.2, C43.+, C44.1, C46.1, C47.1, C49.1, C53.2, C54.2, C55.2, C56.2, C57.1, C58.1, C63.1, C64.1, C65.1, C66.1, C71.1, C72.1, C73.2, D1.G (A), D3.A, D5.D (PIN3), IC3.1 (G), IC3.4 (V-), IC4.15 (GND), IC5.2 (GND), IC6.2 (GND), IC7.3 (GND), IC9.4 (GND), IC10.2 (PGND), IC10.15 (PGND), IC11.2 (GND), IC11.8 (RS), IC13.47 (VSS_1), IC17.2 (GND), IC17.4 (GND), J1.1, JP1.2, JP2.6, JP3.2, JP3.4, JP4.9, JP5.21, JP5.23, JP8.2, JP20.3, L1.2, L7.1, Q4.EMITTER (GND), Q5.7 (O), Q6.EMITTER (GND), Q7.3, Q9.EMITTER (GND), Q11.EMITTER (GND), Q12.EMITTER (GND), Q13.EMITTER (GND), R8.1, R18.1, R21.1, R22.1, R23.1, R26.2, R30.1, R37.1, R55.1, X1.GND, ZD1.C (K)
KELVIN_M: IC13.19 (PB1), JP6.1
KELVIN_P: IC13.18 (PB0), JP7.2
L1: IC13.2 (PC13), Q4.BASE (IN)
L2: IC13.21 (PE8), Q6.BASE (IN)
L3: IC13.22 (PE9), Q9.BASE (IN)
LC_PULSE: IC3.7 (OUT), IC13.35 (PF6), R10.2, R11.2, R13.1
LEFT: C32.2, J2.2
MISO_D14: JP2.1
MOSI_D16: JP2.4
unnamed: C50.2, C51.1, IC12.1 (-IN), R45.2
unnamed: IC16.D (TERMI/NC), R59.1
unnamed: IC7.6 (FB), R36.1, R37.2
unnamed: C22.2, IC7.2 (BST)
unnamed: C42.1, IC11.6 (CANL), L6.2
unnamed: C41.1, IC11.7 (CANH), L6.1
unnamed: R16.1, VR3.3
unnamed: C22.1, R28.1
unnamed: D3.C, IC7.1 (LX), L3.2, R28.2
unnamed: C17.1, IC7.5 (COMP)
unnamed: C17.2, R23.2
unnamed: R42.2, SW1.1
unnamed: C48.1, C50.1, IC12.8 (+IN), R43.2
unnamed: C11.1, IC4.5 (C2-)
unnamed: C11.2, IC4.4 (C2+)
unnamed: C10.2, IC4.2 (V+)
unnamed: IC14.4 (-IN), R52.1, VR4.1
unnamed: D7.D (AC), IC14.1 (OUT), R52.2, R57.1
unnamed: IC7.8 (EN), R20.1, R21.2
unnamed: IC5.5 (OUT), R19.1
unnamed: IC7.4 (FSW), R26.1
unnamed: R50.2, VR4.2
unnamed: IC15.4 (-IN), R53.1, VR5.1
unnamed: C18.1, IC7.7 (SS)
unnamed: D9.D (3), IC13.1 (VBAT), R56.1
unnamed: C7.2, IC4.6 (V-)
unnamed: C8.2, IC4.1 (C+)
unnamed: JP8.1, R19.2
unnamed: C8.1, IC4.3 (C1-)
unnamed: IC2.1 (OUT), Q8.2 (B), R9.1
unnamed: Q12.COLLECTOR (OUT), Q30.8 (2)
unnamed: D8.D (AC), IC15.1 (OUT), R53.2, R58.1
unnamed: R59.2, VR6.2
unnamed: IC13.7 (NRST), R54.1
unnamed: C66.2, IC13.6 (PF1/OSC=>), Q16.3 (2)
unnamed: JP15.2, R44.2, R45.1
unnamed: IC3.5 (BA), IC3.6 (BS)
unnamed: C62.2, C69.2, C70.2, IC13.9 (VDDA/VREF+), IC13.24 (VDDSD), L8.2
unnamed: C6.1, IC3.3 (-IN), R11.1
unnamed: R51.2, VR5.2
unnamed: C26.2, C27.1, IC8.1 (-IN), R27.2
unnamed: C25.1, C26.1, IC8.8 (+IN), R24.2
unnamed: IC10.7 (INL), R38.2
unnamed: IC10.1 (+OUT_L), JP18.1
unnamed: JP12.2, R25.2, R27.1
unnamed: JP12.1, R24.1
unnamed: IC8.6 (OUT), R35.1
unnamed: C4.1, IC3.2 (+IN), R7.1, R8.2, R10.1
unnamed: JP7.1, Q8.3 (C)
unnamed: JP14.1, R40.1
unnamed: JP17.1, R46.1
unnamed: IC10.3 (-OUT_L), JP18.2
unnamed: IC10.14 (-OUT_R), JP19.1
unnamed: IC10.16 (+OUT_R), JP19.2
unnamed: IC10.10 (INR), R34.2
unnamed: C34.1, IC10.8 (VREF)
unnamed: C34.2, J2.1
unnamed: C32.1, R38.1
unnamed: C35.1, F2.P$2 (2), L4.2, X1.VBUS
unnamed: Q14.D (DRAIN), R33.2
unnamed: IC1.D (TERMI/NC), R4.1
unnamed: C20.2, IC6.4 (BP)
unnamed: R4.2, VR1.2
unnamed: R15.1, VR2.3
unnamed: C30.1, R34.1
unnamed: Q10.8 (2), Q11.COLLECTOR (OUT)
unnamed: Q10.4 (S), R15.2
unnamed: C67.1, C68.2, IC13.25 (VREFSD+), IC16.G (V+), R60.2, VR6.1
unnamed: C37.1, IC10.6 (VDD), L5.2
unnamed: IC2.4 (-IN), Q8.1 (E), VR2.2, VR3.2
unnamed: C12.1, J1.2
unnamed: Q10.2 (O), R16.2
unnamed: Q5.4 (S), Q5.5 (S)
unnamed: C1.1, C3.1, C4.2, L2.2, Q5.2 (O)
unnamed: Q7.8 (2), Q9.COLLECTOR (OUT)
unnamed: Q5.8 (2), Q6.COLLECTOR (OUT)
unnamed: Q1.2 (O), Q1.6, Q5.3
unnamed: C1.2, Q7.4 (S)
unnamed: L2.1, Q5.6
unnamed: Q1.8 (2), Q4.COLLECTOR (OUT)
unnamed: JP15.1, R43.1
unnamed: L1.1, Q1.5 (S)
unnamed: JP1.1, Q1.3
unnamed: IC12.6 (OUT), R48.1
unnamed: Q13.COLLECTOR (OUT), Q31.8 (2)
unnamed: JP10.1, Q30.3
unnamed: C65.2, IC13.5 (PF0/OSC<=), Q16.1
unnamed: JP10.2, Q30.2 (O)
unnamed: JP13.1, Q31.3
unnamed: JP13.2, Q31.2 (O)
unnamed: BAT1.+, D9.S (2), R56.2
unnamed: C57.2, IC13.3 (PC14), Q15.1
unnamed: C58.2, IC13.4 (PC15), Q15.4 (2)
PWM1: IC5.4 (-IN), IC13.41 (PB5), R22.2
PWM2: IC13.42 (PB6)
RANGE_SET: IC13.43 (PB7), Q11.BASE (IN)
RELAY1: IC13.36 (PF7), Q12.BASE (IN)
RELAY2: IC13.29 (PA8), Q13.BASE (IN)
RESET: JP2.5
RIGHT: C30.2, J2.3
RXD_LA: IC4.8 (RIN2), IC4.9 (ROUT2), JP9.2, Q2.D, R2.1
RXD_STM: IC4.13 (RIN1), JP11.2
RXI2: IC4.12 (ROUT1), IC13.40 (PB4)
SCK_D15: JP2.3
SCL: IC13.30 (PA9)
SDA: IC13.31 (PA10)
SDADC2_6P: IC13.20 (PB2)
SWCLK: IC13.37 (PA14), JP20.4, R62.1
SWDIO: IC13.34 (PA13), JP20.2, R61.1
TC1_ADC: C38.1, IC13.26 (PB14), R35.2, R39.2
TC2_ADC: C59.1, IC13.27 (PB15), R48.2, R49.2
TXD_LA: IC4.7 (DOUT2), IC4.10 (DIN2), JP9.1, Q3.D, R3.1
TXD_STM: IC4.14 (DOUT1), JP11.1
TXO2: IC4.11 (DIN1), IC13.39 (PB3)
UART_RXI: JP4.5, Q2.S, R5.1
UART_TXO: JP4.7, Q3.S, R6.1
USB_DM: IC13.32 (PA11), R31.1
USB_DP: IC13.33 (PA12), R32.1
USB_EN: IC13.38 (PA15), Q14.G (GATE), R29.1, R30.2
V-OUT: JP22.1, JP23.1, R57.2, R58.2
VDD: JP4.10, Q2.G, Q3.G, R5.2, R6.2
VEE: F1.P$2 (2), J1.3, R17.1
VPP: C14.1, C23.1, C24.2, C73.1, D2.C, IC7.EX_PAD (VIN), IC9.1 (I), IC9.2 (INH), IC17.1 (IN), R20.2
XX: IC13.10 (PA0)
XXX: IC13.12 (PA2)

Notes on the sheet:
+5 Voltage Step Down Regulator
3W STEREO AUDIO AMP
Lattepanda Pin Header
USB
CAN BUS Driver
4-WIRE KELVIN
K-Type Range = -180°C to 1200°C
1.24V REF = -248°C to 752°C
0.9V REF = -180°C to 820°C
0V REF = 0°C to 1000°C
LC METER
DAC
THERMO COUPLE K-TYPE
CH1
CH2
RS232C
REGULATOR

Board: 2 copper layers, 222 parts (1 on the bottom side), 146 nets, no tracks yet.

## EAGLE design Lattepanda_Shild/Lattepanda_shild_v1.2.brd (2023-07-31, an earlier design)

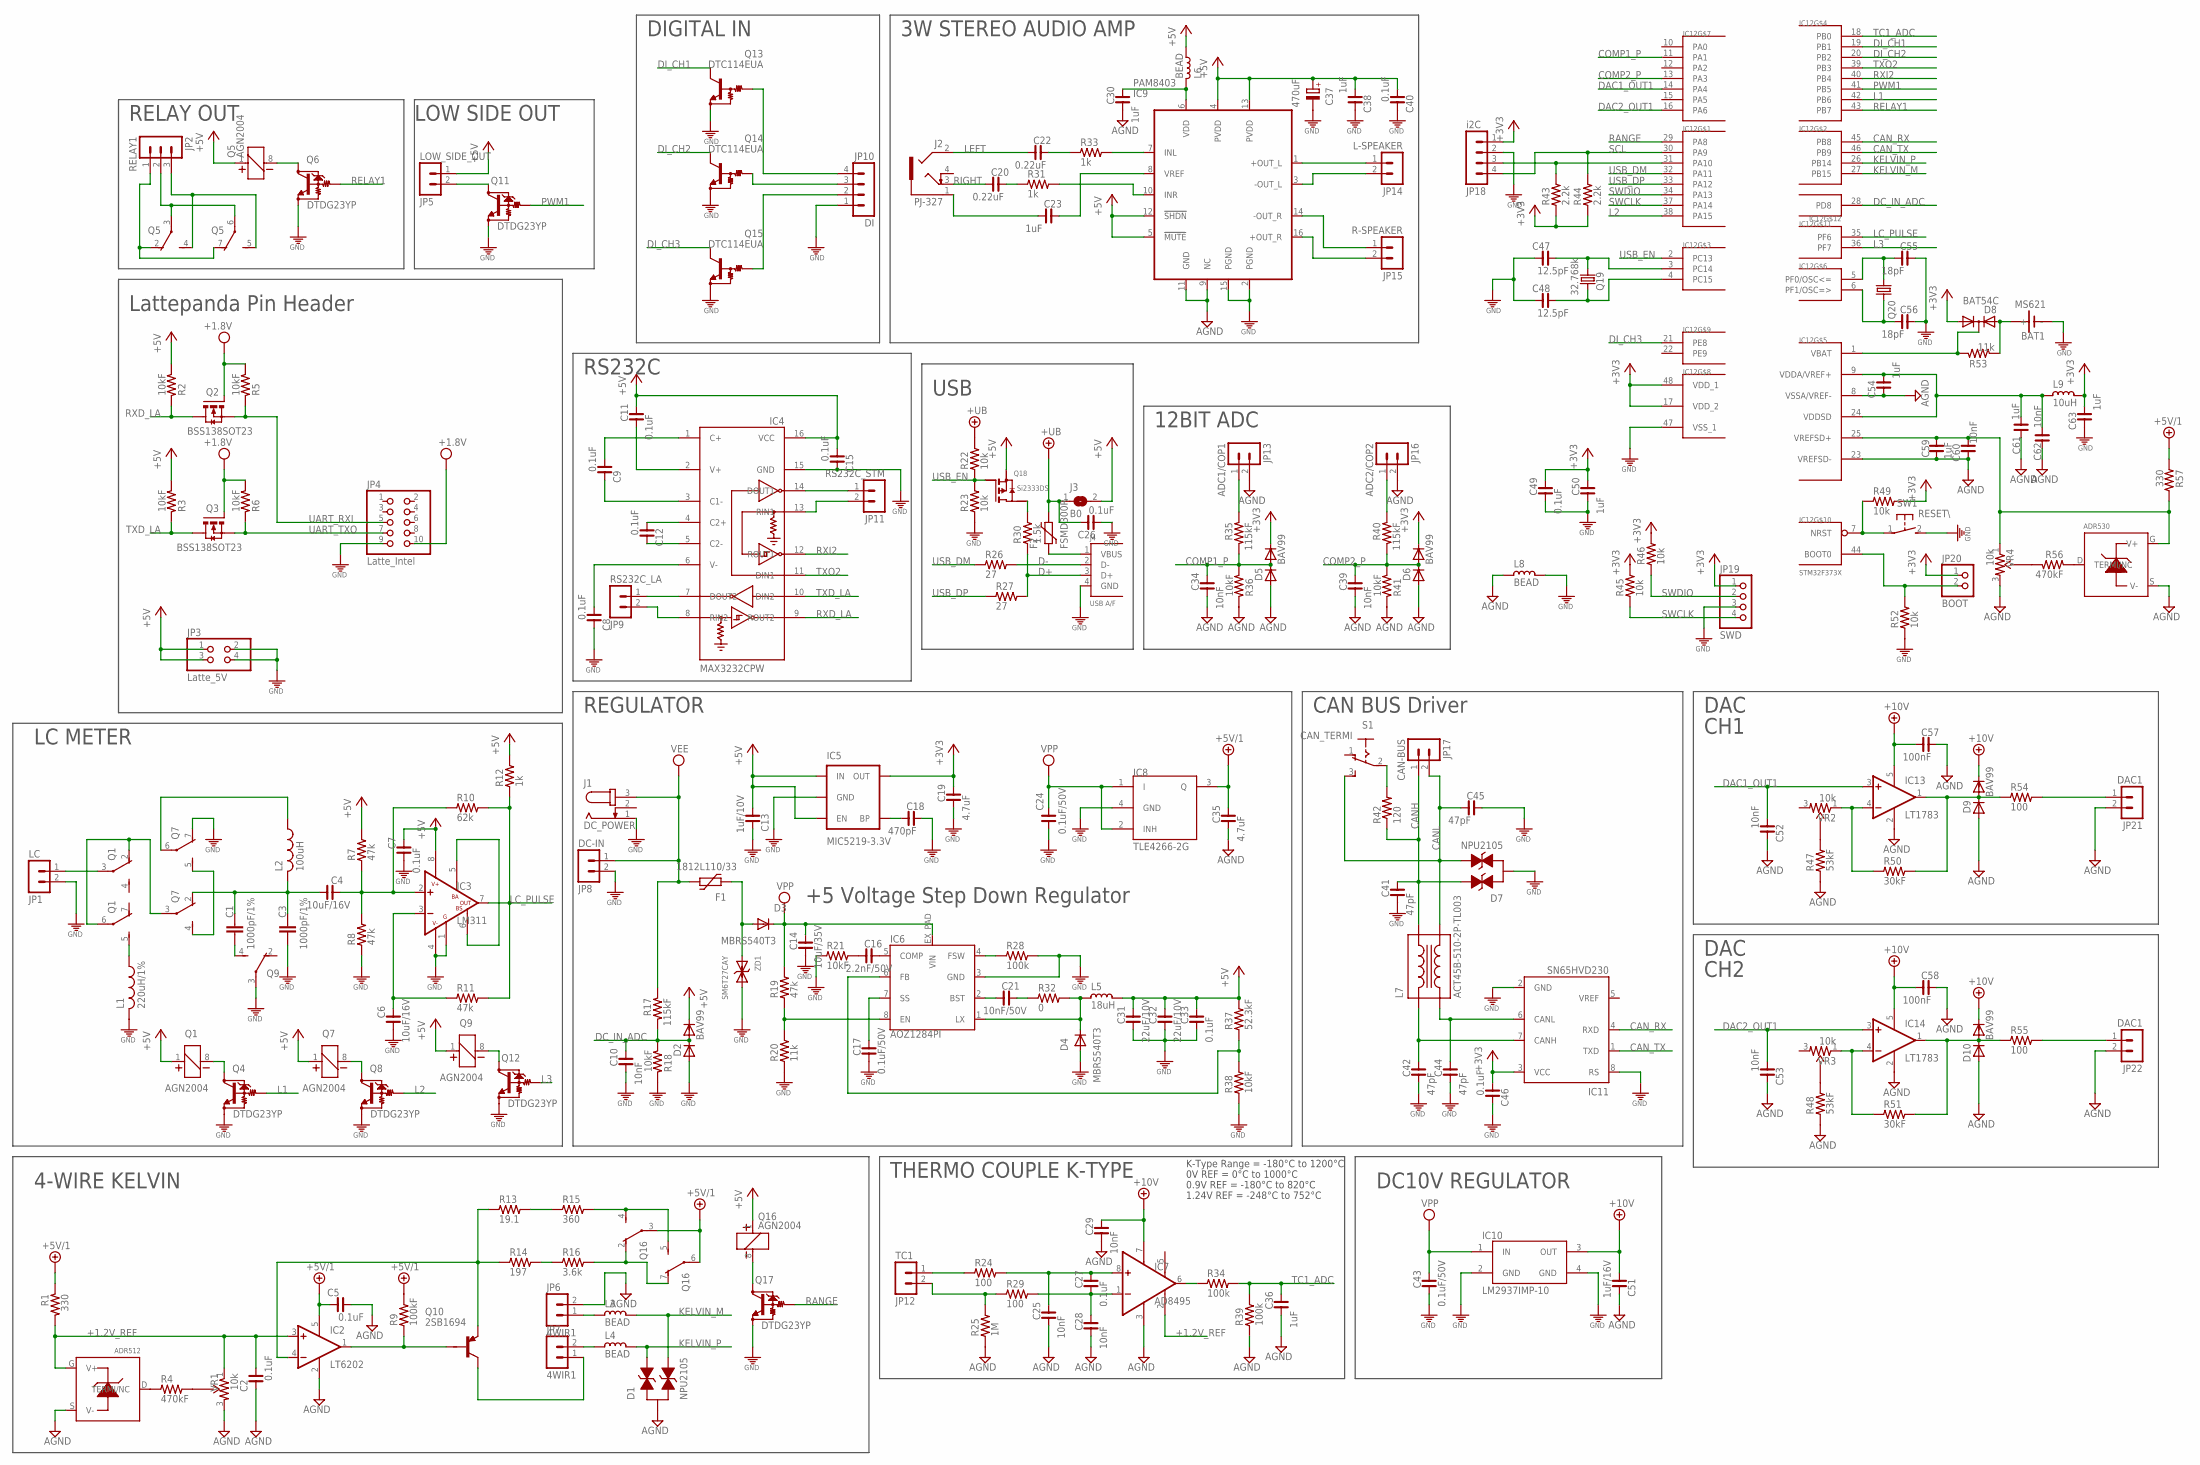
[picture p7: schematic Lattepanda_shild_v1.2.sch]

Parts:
BAT1: MS621
C1, C3: 1000pF/1%; C050-025X075
C2, C5, C7, C8, C9, C11, C12, C15, C26, C27, C33, C40, C46, C49: 0.1uF; C0603
C4, C6: 10uF/16V; C3216
C10, C25, C28, C29, C34, C39, C52, C53, C60, C62: 10nF; C0603
C13: 1uF/10V; C0603
C14: 10uF/35V; C3225
C16: 2.2nF/50V; C0603
C17, C43: 0.1uF/50V; C0603
C18: 470pF; C0603
C19, C35: 4.7uF; C2012
C20, C22: 0.22uF; C0603
C21: 10nF/50V; C0603
C23, C30, C36, C38, C50, C54, C59, C61, C63: 1uF; C0603
C24: 0.1uF/50V; C1608-
C31, C32: 22uF/10V; C3216
C37: 470uF; D/7343-31W
C41, C42, C44, C45: 47pF; C0603
C47, C48: 12.5pF; C0603
C51: 1uF/16V; C0603
C55, C56: 18pF; C0603
C57, C58: 100nF; C0603
D1, D7: NPU2105; SOT23
D2, D5, D6, D9, D10: BAV99; SOT23
D3, D4: MBRS540T3; SMC
D8: BAT54C; SOT23
F1: 1812L110/33; 1812L
F2: FSMD300R; 1812L
IC1: ADR512; SOT23
IC2: LT6202; SOT23-5L
IC3: LM311; SO8
IC4: MAX3232CPW; PW_R-PDSO-G16
IC5: MIC5219-3.3V; SOT23-5
IC6: AOZ1284PI; S08-EP1
IC7: AD8495; MSOP8
IC8: TLE4266-2G; SOT223-4
IC9: PAM8403; SOIC16N
IC10: LM2937IMP-10; SOT223
IC11: SN65HVD230; SO8
IC12: STM32F373X; TQFP48
IC13, IC14: LT1783; SOT23-5
IC15: ADR530; SOT23
J1: DC_POWER; SPC4077
J2: PJ-327; PJ-327-2
J3: B0; SJ
J4: USB A/F; USB_AF_SIDE
JP1: LC; ED350V-02P
JP2: RELAY1; ED350V-03P
JP3: Latte_5V; 2X02
JP4: Latte_Intel; 2X05M
JP5: LOW_SIDE_OUT; ED350V-02P
JP6, JP7: 4WIR1; ED350V-02P
JP8: DC-IN; ED350V-02P
JP9: RS232C_LA; ED350V-02P
JP10: DI; 53047-04
JP11: RS232C_STM; ED350V-02P
JP12: TC1; ED350V-02P
JP13: ADC1/COP1; ED350V-02P
JP14: L-SPEAKER; ED350V-02P
JP15: R-SPEAKER; ED350V-02P
JP16: ADC2/COP2; ED350V-02P
JP17: CAN-BUS; ED350V-02P
JP18: i2C; MOLEX5267-04
JP19: SWD; 1X04M
JP20: BOOT; 1X02M
JP21, JP22: DAC1; ED350V-02P
L1: 220uH/1%; 0207/2V
L2: 100uH; 0207/2V
L3, L4, L8: BEAD; L0603
L5: 18uH; SHP1260P-F
L6: BEAD; L0805
L7: ACT45B-510-2P-TL003; ACT45B
L9: 10uH; L0805
Q1, Q5, Q7, Q9, Q16: AGN2004; ANG200X
Q2, Q3: BSS138SOT23; SOT23
Q4, Q6, Q8, Q11, Q12, Q17: DTDG23YP; MPT3
Q10: 2SB1694; SOT323
Q13, Q14, Q15: DTC114EUA; SC59-BEC
Q18: Si2333DS; SOT23
Q19: 32.768k; MC-306
Q20: 8MHz; SMD5032
R1, R57: 330; R0603
R2, R3, R5, R6, R18, R21, R36, R38, R41: 10kF; R0603
R4, R56: 470kF; R0603
R7, R8, R11, R19: 47k; R0603
R9: 100kF; R0603
R10: 62k; R0603
R12, R31, R33: 1k; R0603
R13: 19.1; R0603
R14: 197; R0603
R15: 360; R0603
R16: 3.6k; R0603
R17, R35, R40: 115kF; R0603
R20, R53: 11k; R0603
R22, R23, R45, R46, R49, R52: 10k; R0603
R24, R29, R54, R55: 100; R0603
R25: 1M; R0603
R26, R27: 27; R0603
R28, R34, R39: 100k; R0603
R30: 1.5k; R0603
R32: 0; R0603
R37: 52.3kF; R0603
R42: 120; R0603@1
R43, R44: 2.2k; R0603
R47, R48: 53kF; R0603
R50, R51: 30kF; R0603
S1: CAN_TERMI; 255SB
SW1: RESET\; DTSM-3
VR1, VR4: 10k; 3266W
VR2, VR3: 10k; R-TRIMMER-3313J
ZD1: SM6T27CAY; SMB

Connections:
+1.2V_REF: C2.2, IC1.G (V+), IC2.3 (+IN), IC7.2 (REF), R1.2, VR1.1
+3V3: C19.1, C46.2, C49.1, C50.1, C63.2, D5.S (C), D6.S (C), D8.G (1), IC5.5 (OUT), IC11.3 (VCC), IC12.17 (VDD_2), IC12.48 (VDD_1), JP18.1, JP19.1, JP20.1, L9.1, R43.1, R44.1, R45.2, R46.2, R49.2
+5V: C7.1, C11.1, C13.2, C15.2, C31.1, C32.1, C33.1, C37.+, C38.2, C40.2, D2.S (C), IC3.8 (V+), IC4.16 (VCC), IC5.1 (IN), IC5.3 (EN), IC9.4 (PVDD), IC9.5 (!MUTE), IC9.12 (!SHDN), IC9.13 (PVDD), J3.2, JP3.1, JP3.3, JP5.1, L5.1, L6.1, Q1.1, Q5.1, Q7.1, Q9.1, Q16.1, Q18.S (SOURCE), R2.2, R3.2, R7.2, R12.2, R37.2
+5V/1: C5.1, C35.1, IC2.5 (V+), IC8.3 (Q), Q16.3, Q16.6, R1.1, R9.2, R57.1
+10V: C29.1, C51.2, C57.2, C58.2, D9.S (C), D10.S (C), IC7.7 (V+), IC10.3 (OUT), IC13.5 (V+), IC14.5 (V+)
+UB: C26.1, F2.P$2 (2), J3.1, R22.2
AGND: C2.1, C5.2, C25.2, C28.2, C29.2, C30.2, C34.2, C35.2, C36.2, C39.2, C51.1, C52.1, C53.1, C54.1, C57.1, C58.1, C59.2, C60.1, C61.1, C62.1, D1.D (PIN3), D5.G (A), D6.G (A), D9.G (A), D10.G (A), IC1.S (V-), IC2.2 (V-), IC7.3 (V-), IC9.9 (NC), IC9.11 (GND), IC12.8 (VSSA/VREF-), IC12.23 (VREFSD-), IC13.2 (V-), IC14.2 (V-), IC15.S (V-), JP6.2, JP13.2, JP16.2, JP21.2, JP22.2, L8.2, R25.1, R36.1, R39.1, R41.1, R47.1, R48.1, VR1.3, VR4.3
BOOT1: IC12.44 (BOOT0), JP20.2, R52.2
CANH: C41.1, D7.G (PIN1), JP17.1, L7.4, R42.1
CANL: C45.2, D7.S (PIN2), JP17.2, L7.3, S1.3 (S)
CAN_RX: IC11.4 (RXD), IC12.45 (PB8)
CAN_TX: IC11.1 (TXD), IC12.46 (PB9)
COMP1_P: C34.1, D5.D (AC), IC12.11 (PA1), R35.2, R36.2
COMP2_P: C39.1, D6.D (AC), IC12.13 (PA3), R40.2, R41.2
D+: J4.3 (D+), R27.2, R30.1
D-: J4.2 (D-), R26.2
DAC1_OUT1: C52.2, IC12.14 (PA4), IC13.3 (+IN)
DAC2_OUT1: C53.2, IC12.16 (PA6), IC14.3 (+IN)
DC-IN: D3.A, F1.P$1 (1), ZD1.A
DC_IN_ADC: C10.1, D2.D (AC), IC12.28 (PD8), R17.2, R18.2
DI_CH1: IC12.19 (PB1), Q13.3 (OUT)
DI_CH2: IC12.20 (PB2), Q14.3 (OUT)
DI_CH3: IC12.21 (PE8), Q15.3 (OUT)
GND: BAT1.-, C3.2, C6.2, C7.2, C8.1, C10.2, C13.1, C14.2, C15.1, C17.2, C18.1, C19.2, C24.1, C26.2, C31.2, C32.2, C33.2, C37.-, C38.1, C40.1, C41.2, C42.2, C43.2, C44.2, C45.1, C46.1, C47.1, C48.1, C49.2, C50.2, C55.1, C56.1, C63.1, D2.G (A), D4.A, D7.D (PIN3), IC3.1 (G), IC3.4 (V-), IC4.15 (GND), IC5.2 (GND), IC6.3 (GND), IC8.4 (GND), IC9.2 (PGND), IC9.15 (PGND), IC10.2 (GND), IC10.4 (GND), IC11.2 (GND), IC11.8 (RS), IC12.47 (VSS_1), J1.1, J4.4 (GND), JP1.2, JP3.2, JP3.4, JP4.9, JP8.2, JP10.1, JP18.2, JP19.3, L1.2, L8.1, Q4.EMITTER (GND), Q6.EMITTER (GND), Q7.7 (O), Q8.EMITTER (GND), Q9.3, Q11.EMITTER (GND), Q12.EMITTER (GND), Q13.1 (GND), Q14.1 (GND), Q15.1 (GND), Q17.EMITTER (GND), R8.1, R18.1, R20.1, R21.1, R23.1, R28.2, R38.1, R52.1, SW1.2, ZD1.C (K)
KELVIN_M: D1.S (PIN2), IC12.27 (PB15), L3.1
KELVIN_P: D1.G (PIN1), IC12.26 (PB14), L4.1
L1: IC12.42 (PB6), Q4.BASE (IN)
L2: IC12.38 (PA15), Q8.BASE (IN)
L3: IC12.36 (PF7), Q12.BASE (IN)
LC_PULSE: IC3.7 (OUT), IC12.35 (PF6), R10.2, R11.2, R12.1
LEFT: C22.2, J2.2
unnamed: JP5.2, Q11.COLLECTOR (OUT)
unnamed: IC15.D (TERMI/NC), R56.1
unnamed: IC6.6 (FB), R37.1, R38.2
unnamed: C21.2, IC6.2 (BST)
unnamed: C44.1, IC11.6 (CANL), L7.2
unnamed: C42.1, IC11.7 (CANH), L7.1
unnamed: R14.2, R16.1
unnamed: C21.1, R32.1
unnamed: D4.C, IC6.1 (LX), L5.2, R32.2
unnamed: C16.1, IC6.5 (COMP)
unnamed: C16.2, R21.2
unnamed: R42.2, S1.2
unnamed: R48.2, VR3.2
unnamed: C12.1, IC4.5 (C2-)
unnamed: C12.2, IC4.4 (C2+)
unnamed: C11.2, IC4.2 (V+)
unnamed: IC14.4 (-IN), R51.1, VR3.1
unnamed: D10.D (AC), IC14.1 (OUT), R51.2, R55.1
unnamed: IC6.8 (EN), R19.1, R20.2
unnamed: JP6.1, L3.2
unnamed: IC6.4 (FSW), R28.1
unnamed: JP7.2, L4.2
unnamed: C17.1, IC6.7 (SS)
unnamed: D8.D (3), IC12.1 (VBAT), R53.1
unnamed: C8.2, IC4.6 (V-)
unnamed: C9.2, IC4.1 (C+)
unnamed: IC4.8 (RIN2), JP9.2
unnamed: C9.1, IC4.3 (C1-)
unnamed: IC2.1 (OUT), Q10.2 (B), R9.1
unnamed: Q5.8 (2), Q6.COLLECTOR (OUT)
unnamed: IC4.7 (DOUT2), JP9.1
unnamed: R56.2, VR4.2
unnamed: IC12.7 (NRST), R49.1, SW1.1
unnamed: C56.2, IC12.6 (PF1/OSC=>), Q20.3 (2)
unnamed: IC4.13 (RIN1), JP11.2
unnamed: IC3.5 (BA), IC3.6 (BS)
unnamed: C54.2, C61.2, C62.2, IC12.9 (VDDA/VREF+), IC12.24 (VDDSD), L9.2
unnamed: C6.1, IC3.3 (-IN), R11.1
unnamed: IC4.14 (DOUT1), JP11.1
unnamed: C27.2, C28.1, IC7.1 (-IN), R29.2
unnamed: C25.1, C27.1, IC7.8 (+IN), R24.2
unnamed: IC9.7 (INL), R33.2
unnamed: IC9.1 (+OUT_L), JP14.1
unnamed: JP12.2, R25.2, R29.1
unnamed: JP12.1, R24.1
unnamed: IC7.6 (OUT), R34.1
unnamed: C4.1, IC3.2 (+IN), R7.1, R8.2, R10.1
unnamed: JP7.1, Q10.3 (C)
unnamed: JP13.1, R35.1
unnamed: JP16.1, R40.1
unnamed: IC9.3 (-OUT_L), JP14.2
unnamed: IC9.14 (-OUT_R), JP15.1
unnamed: IC9.16 (+OUT_R), JP15.2
unnamed: IC9.10 (INR), R31.2
unnamed: C23.1, IC9.8 (VREF)
unnamed: C23.2, J2.1
unnamed: C22.1, R33.1
unnamed: F2.P$1 (1), J4.1 (VBUS)
unnamed: JP21.1, R54.2
unnamed: IC1.D (TERMI/NC), R4.1
unnamed: C18.2, IC5.4 (BP)
unnamed: R4.2, VR1.2
unnamed: R13.2, R15.1
unnamed: C20.1, R31.1
unnamed: Q16.8 (2), Q17.COLLECTOR (OUT)
unnamed: Q16.4 (S), Q16.5 (S), R15.2
unnamed: C59.1, C60.2, IC12.25 (VREFSD+), IC15.G (V+), R57.2, VR4.1
unnamed: C30.1, IC9.6 (VDD), L6.2
unnamed: IC2.4 (-IN), Q10.1 (E), R13.1, R14.1
unnamed: IC13.4 (-IN), R50.1, VR2.1
unnamed: Q16.2 (O), Q16.7 (O), R16.2
unnamed: Q7.4 (S), Q7.5 (S)
unnamed: C1.1, C3.1, C4.2, L2.2, Q7.2 (O)
unnamed: Q9.8 (2), Q12.COLLECTOR (OUT)
unnamed: Q7.8 (2), Q8.COLLECTOR (OUT)
unnamed: Q1.2 (O), Q1.6, Q7.3
unnamed: C1.2, Q9.4 (S)
unnamed: L2.1, Q7.6
unnamed: Q1.8 (2), Q4.COLLECTOR (OUT)
unnamed: Q18.D (DRAIN), R30.2
unnamed: L1.1, Q1.5 (S)
unnamed: JP1.1, Q1.3
unnamed: D9.D (AC), IC13.1 (OUT), R50.2, R54.1
unnamed: R47.2, VR2.2
unnamed: JP2.2, Q5.3, Q5.6
unnamed: C55.2, IC12.5 (PF0/OSC<=), Q20.1
unnamed: JP2.1, Q5.2 (O), Q5.7 (O)
unnamed: JP2.3, Q5.4 (S), Q5.5 (S)
unnamed: JP22.1, R55.2
unnamed: IC12.31 (PA10), JP18.3, R43.2
unnamed: BAT1.+, D8.S (2), R53.2
unnamed: JP10.2, Q15.2 (IN)
unnamed: JP10.3, Q14.2 (IN)
unnamed: C47.2, IC12.3 (PC14), Q19.1
unnamed: C48.2, IC12.4 (PC15), Q19.4 (2)
unnamed: JP10.4, Q13.2 (IN)
PWM1: IC12.41 (PB5), Q11.BASE (IN)
RANGE: IC12.29 (PA8), Q17.BASE (IN)
RELAY1: IC12.43 (PB7), Q6.BASE (IN)
RIGHT: C20.2, J2.3
RXD_LA: IC4.9 (ROUT2), Q2.D, R2.1
RXI2: IC4.12 (ROUT1), IC12.40 (PB4)
SCL: IC12.30 (PA9), JP18.4, R44.2
SWCLK: IC12.37 (PA14), JP19.4, R45.1
SWDIO: IC12.34 (PA13), JP19.2, R46.1
TC1_ADC: C36.1, IC12.18 (PB0), R34.2, R39.2
TXD_LA: IC4.10 (DIN2), Q3.D, R3.1
TXO2: IC4.11 (DIN1), IC12.39 (PB3)
UART_RXI: JP4.5, Q2.S, R5.1
UART_TXO: JP4.7, Q3.S, R6.1
USB_DM: IC12.32 (PA11), R26.1
USB_DP: IC12.33 (PA12), R27.1
USB_EN: IC12.2 (PC13), Q18.G (GATE), R22.1, R23.2
VDD: JP4.10, Q2.G, Q3.G, R5.2, R6.2
VEE: F1.P$2 (2), J1.3, JP8.1, R17.1
VPP: C14.1, C24.2, C43.1, D3.C, IC6.EX_PAD (VIN), IC8.1 (I), IC8.2 (INH), IC10.1 (IN), R19.2

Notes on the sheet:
+5 Voltage Step Down Regulator
3W STEREO AUDIO AMP
Lattepanda Pin Header
USB
CAN BUS Driver
4-WIRE KELVIN
K-Type Range = -180°C to 1200°C
1.24V REF = -248°C to 752°C
0.9V REF = -180°C to 820°C
0V REF = 0°C to 1000°C
LC METER
DAC
THERMO COUPLE K-TYPE
RS232C
REGULATOR
DC10V REGULATOR
12BIT ADC
CH1
CH2
LOW SIDE OUT
RELAY OUT
DIGITAL IN

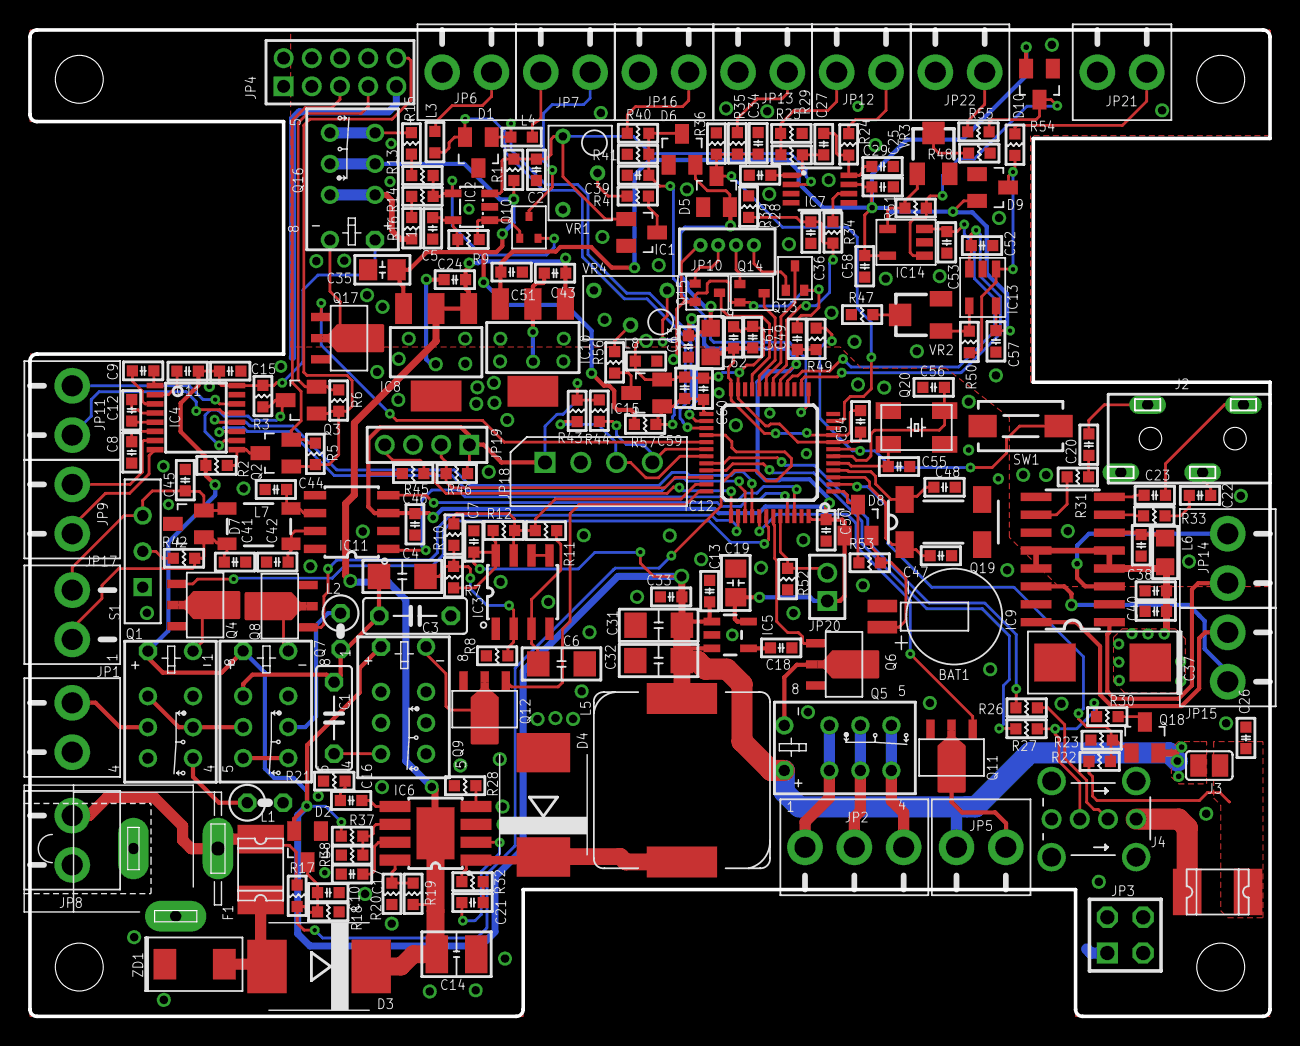
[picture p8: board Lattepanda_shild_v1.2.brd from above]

Board: 2 copper layers, 88.0 x 70.0 mm, 210 parts (0 on the bottom side), 147 nets.

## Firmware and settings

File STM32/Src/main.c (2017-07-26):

/**
  ******************************************************************************
  * File Name          : main.c
  * Description        : Main program body
  ******************************************************************************
  * This notice applies to any and all portions of this file
  * that are not between comment pairs USER CODE BEGIN and
  * USER CODE END. Other portions of this file, whether 
  * inserted by the user or by software development tools
  * are owned by their respective copyright owners.
  *
  * Copyright (c) 2017 STMicroelectronics International N.V. 
  * All rights reserved.
  *
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
  ******************************************************************************
  */
/* Includes ------------------------------------------------------------------*/
#include "main.h"
#include "stm32f3xx_hal.h"
#include "cmsis_os.h"
#include "usb_device.h"

/* USER CODE BEGIN Includes */
#include "board.h"
#include "usbd_cdc_if.h"
#include "rtc.h"
#include <mavlink/Lattepanda_shiled/mavlink.h>

/* USER CODE END Includes */

ADC_HandleTypeDef hadc1;
DMA_HandleTypeDef hdma_adc1;

CAN_HandleTypeDef hcan;

DAC_HandleTypeDef hdac1;
DAC_HandleTypeDef hdac2;

I2C_HandleTypeDef hi2c2;

RTC_HandleTypeDef hrtc;

SDADC_HandleTypeDef hsdadc1;
SDADC_HandleTypeDef hsdadc3;
DMA_HandleTypeDef hdma_sdadc1;
DMA_HandleTypeDef hdma_sdadc3;

TIM_HandleTypeDef htim3;
TIM_HandleTypeDef htim4;
TIM_HandleTypeDef htim5;
TIM_HandleTypeDef htim19;

UART_HandleTypeDef huart2;
DMA_HandleTypeDef hdma_usart2_rx;
DMA_HandleTypeDef hdma_usart2_tx;

osThreadId defaultTaskHandle;
osThreadId Task_1msHandle;

/* USER CODE BEGIN PV */



/* USER CODE END PV */

void SystemClock_Config(void);
static void MX_GPIO_Init(void);
static void MX_DMA_Init(void);
static void MX_CAN_Init(void);
static void MX_DAC1_Init(void);
static void MX_DAC2_Init(void);
static void MX_SDADC3_Init(void);
static void MX_RTC_Init(void);
static void MX_SDADC1_Init(void);
static void MX_I2C2_Init(void);
static void MX_ADC1_Init(void);
static void MX_USART2_UART_Init(void);
static void MX_TIM4_Init(void);
static void MX_TIM3_Init(void);
static void MX_TIM5_Init(void);
static void MX_TIM19_Init(void);
void StartDefaultTask(void const * argument);
void Tick1_Task(void const * argument);

void HAL_TIM_MspPostInit(TIM_HandleTypeDef *htim);
                                

/* USER CODE BEGIN PFP */

/* USER CODE END PFP */

/* USER CODE BEGIN 0 */


uint32_t Raw_ICP;


//uint32_t VCP_Tick=0;


/* USER CODE END 0 */

int main(void)
{

  /* MCU Configuration----------------------------------------------------------*/

  /* Reset of all peripherals, Initializes the Flash interface and the Systick. */
  HAL_Init();

  /* USER CODE BEGIN Init */
		initEEPROM();
		checkFirstTime(false);
		readEEPROM();	
		output_protocl_port_init();
		initSystemset();
  /* USER CODE END Init */

  /* Configure the system clock */
  SystemClock_Config();

  /* USER CODE BEGIN SysInit */
	
//		if(HAL_RTC_DeInit(&hrtc)!=HAL_OK) {
//				MX_RTC_Init();
//		}
//		else {
//		}

  /* USER CODE END SysInit */

  /* Initialize all configured peripherals */
  MX_GPIO_Init();
  MX_DMA_Init();
  MX_CAN_Init();
  MX_DAC1_Init();
  MX_DAC2_Init();
  MX_SDADC3_Init();
  MX_RTC_Init();
  MX_SDADC1_Init();
  MX_I2C2_Init();
  MX_ADC1_Init();
  MX_USART2_UART_Init();
  MX_TIM4_Init();
  MX_TIM3_Init();
  MX_TIM5_Init();
  MX_TIM19_Init();

  /* USER CODE BEGIN 2 */
	systemInit();
	USB_DECTETION_DISABLE;
		C_CTL_HIGH;
		

	
//	xTaskCreate(vDAC_Task, "DAC_Task", 64, NULL, 2, NULL);
//	xTaskCreate(LC_Task, "SDADC_Task", 128, NULL, 0, NULL);
//	xTaskCreate(vADC_Task, "ADC1_Task", 128, NULL, 3, NULL);
//	xTaskCreate(VCP_Task, "USB_Task", 128, NULL, 1, NULL);
////	
//	vTaskStartScheduler();
  /* USER CODE END 2 */

  /* USER CODE BEGIN RTOS_MUTEX */
  /* add mutexes, ... */
  /* USER CODE END RTOS_MUTEX */

  /* USER CODE BEGIN RTOS_SEMAPHORES */
  /* add semaphores, ... */
  /* USER CODE END RTOS_SEMAPHORES */

  /* USER CODE BEGIN RTOS_TIMERS */
  /* start timers, add new ones, ... */
  /* USER CODE END RTOS_TIMERS */

  /* Create the thread(s) */
  /* definition and creation of defaultTask */
  osThreadDef(defaultTask, StartDefaultTask, osPriorityNormal, 0, 300);
  defaultTaskHandle = osThreadCreate(osThread(defaultTask), NULL);

  /* definition and creation of Task_1ms */
  osThreadDef(Task_1ms, Tick1_Task, osPriorityHigh, 0, 240);
  Task_1msHandle = osThreadCreate(osThread(Task_1ms), NULL);

  /* USER CODE BEGIN RTOS_THREADS */
  /* add threads, ... */
  /* USER CODE END RTOS_THREADS */

  /* USER CODE BEGIN RTOS_QUEUES */
  /* add queues, ... */
  /* USER CODE END RTOS_QUEUES */
 

  /* Start scheduler */
  osKernelStart();
  
  /* We should never get here as control is now taken by the scheduler */

  /* Infinite loop */
  /* USER CODE BEGIN WHILE */


		while (1)
  {
  /* USER CODE END WHILE */

  /* USER CODE BEGIN 3 */

		
  }
  /* USER CODE END 3 */

}

/** System Clock Configuration
*/
void SystemClock_Config(void)
{

  RCC_OscInitTypeDef RCC_OscInitStruct;
  RCC_ClkInitTypeDef RCC_ClkInitStruct;
  RCC_PeriphCLKInitTypeDef PeriphClkInit;

    /**Configure LSE Drive Capability 
    */
  __HAL_RCC_LSEDRIVE_CONFIG(RCC_LSEDRIVE_LOW);

    /**Initializes the CPU, AHB and APB busses clocks 
    */
  RCC_OscInitStruct.OscillatorType = RCC_OSCILLATORTYPE_HSI|RCC_OSCILLATORTYPE_HSE
                              |RCC_OSCILLATORTYPE_LSE;
  RCC_OscInitStruct.HSEState = RCC_HSE_ON;
  RCC_OscInitStruct.HSEPredivValue = RCC_HSE_PREDIV_DIV1;
  RCC_OscInitStruct.LSEState = RCC_LSE_ON;
  RCC_OscInitStruct.HSIState = RCC_HSI_ON;
  RCC_OscInitStruct.HSICalibrationValue = 16;
  RCC_OscInitStruct.PLL.PLLState = RCC_PLL_ON;
  RCC_OscInitStruct.PLL.PLLSource = RCC_PLLSOURCE_HSE;
  RCC_OscInitStruct.PLL.PLLMUL = RCC_PLL_MUL9;
  if (HAL_RCC_OscConfig(&RCC_OscInitStruct) != HAL_OK)
  {
    _Error_Handler(__FILE__, __LINE__);
  }

    /**Initializes the CPU, AHB and APB busses clocks 
    */
  RCC_ClkInitStruct.ClockType = RCC_CLOCKTYPE_HCLK|RCC_CLOCKTYPE_SYSCLK
                              |RCC_CLOCKTYPE_PCLK1|RCC_CLOCKTYPE_PCLK2;
  RCC_ClkInitStruct.SYSCLKSource = RCC_SYSCLKSOURCE_PLLCLK;
  RCC_ClkInitStruct.AHBCLKDivider = RCC_SYSCLK_DIV1;
  RCC_ClkInitStruct.APB1CLKDivider = RCC_HCLK_DIV2;
  RCC_ClkInitStruct.APB2CLKDivider = RCC_HCLK_DIV1;

  if (HAL_RCC_ClockConfig(&RCC_ClkInitStruct, FLASH_LATENCY_2) != HAL_OK)
  {
    _Error_Handler(__FILE__, __LINE__);
  }

  PeriphClkInit.PeriphClockSelection = RCC_PERIPHCLK_USB|RCC_PERIPHCLK_USART2
                              |RCC_PERIPHCLK_I2C2|RCC_PERIPHCLK_RTC
                              |RCC_PERIPHCLK_ADC1|RCC_PERIPHCLK_SDADC;
  PeriphClkInit.Usart2ClockSelection = RCC_USART2CLKSOURCE_PCLK1;
  PeriphClkInit.I2c2ClockSelection = RCC_I2C2CLKSOURCE_HSI;
  PeriphClkInit.RTCClockSelection = RCC_RTCCLKSOURCE_LSE;
  PeriphClkInit.USBClockSelection = RCC_USBCLKSOURCE_PLL_DIV1_5;
  PeriphClkInit.SdadcClockSelection = RCC_SDADCSYSCLK_DIV12;
  PeriphClkInit.Adc1ClockSelection = RCC_ADC1PCLK2_DIV6;

  if (HAL_RCCEx_PeriphCLKConfig(&PeriphClkInit) != HAL_OK)
  {
    _Error_Handler(__FILE__, __LINE__);
  }

  HAL_PWREx_EnableSDADC(PWR_SDADC_ANALOG1);

  HAL_PWREx_EnableSDADC(PWR_SDADC_ANALOG3);

    /**Configure the Systick interrupt time 
    */
  HAL_SYSTICK_Config(HAL_RCC_GetHCLKFreq()/1000);

    /**Configure the Systick 
    */
  HAL_SYSTICK_CLKSourceConfig(SYSTICK_CLKSOURCE_HCLK);

  /* SysTick_IRQn interrupt configuration */
  HAL_NVIC_SetPriority(SysTick_IRQn, 15, 0);
}

/* ADC1 init function */
static void MX_ADC1_Init(void)
{

  ADC_ChannelConfTypeDef sConfig;

    /**Common config 
    */
  hadc1.Instance = ADC1;
  hadc1.Init.ScanConvMode = ADC_SCAN_ENABLE;
  hadc1.Init.ContinuousConvMode = ENABLE;
  hadc1.Init.DiscontinuousConvMode = DISABLE;
  hadc1.Init.ExternalTrigConv = ADC_SOFTWARE_START;
  hadc1.Init.DataAlign = ADC_DATAALIGN_RIGHT;
  hadc1.Init.NbrOfConversion = 2;
  if (HAL_ADC_Init(&hadc1) != HAL_OK)
  {
    _Error_Handler(__FILE__, __LINE__);
  }

    /**Configure Regular Channel 
    */
  sConfig.Channel = ADC_CHANNEL_1;
  sConfig.Rank = 1;
  sConfig.SamplingTime = ADC_SAMPLETIME_239CYCLES_5;
  if (HAL_ADC_ConfigChannel(&hadc1, &sConfig) != HAL_OK)
  {
    _Error_Handler(__FILE__, __LINE__);
  }

    /**Configure Regular Channel 
    */
  sConfig.Channel = ADC_CHANNEL_3;
  sConfig.Rank = 2;
  if (HAL_ADC_ConfigChannel(&hadc1, &sConfig) != HAL_OK)
  {
    _Error_Handler(__FILE__, __LINE__);
  }

}

/* CAN init function */
static void MX_CAN_Init(void)
{

  hcan.Instance = CAN;
  hcan.Init.Prescaler = 9;
  hcan.Init.Mode = CAN_MODE_NORMAL;
  hcan.Init.SJW = CAN_SJW_1TQ;
  hcan.Init.BS1 = CAN_BS1_6TQ;
  hcan.Init.BS2 = CAN_BS2_1TQ;
  hcan.Init.TTCM = DISABLE;
  hcan.Init.ABOM = ENABLE;
  hcan.Init.AWUM = DISABLE;
  hcan.Init.NART = DISABLE;
  hcan.Init.RFLM = DISABLE;
  hcan.Init.TXFP = DISABLE;
  if (HAL_CAN_Init(&hcan) != HAL_OK)
  {
    _Error_Handler(__FILE__, __LINE__);
  }

}

/* DAC1 init function */
static void MX_DAC1_Init(void)
{

  DAC_ChannelConfTypeDef sConfig;

    /**DAC Initialization 
    */
  hdac1.Instance = DAC1;
  if (HAL_DAC_Init(&hdac1) != HAL_OK)
  {
    _Error_Handler(__FILE__, __LINE__);
  }

    /**DAC channel OUT1 config 
    */
  sConfig.DAC_Trigger = DAC_TRIGGER_NONE;
  sConfig.DAC_OutputBuffer = DAC_OUTPUTBUFFER_DISABLE;
  if (HAL_DAC_ConfigChannel(&hdac1, &sConfig, DAC_CHANNEL_1) != HAL_OK)
  {
    _Error_Handler(__FILE__, __LINE__);
  }

}

/* DAC2 init function */
static void MX_DAC2_Init(void)
{

  DAC_ChannelConfTypeDef sConfig;

    /**DAC Initialization 
    */
  hdac2.Instance = DAC2;
  if (HAL_DAC_Init(&hdac2) != HAL_OK)
  {
    _Error_Handler(__FILE__, __LINE__);
  }

    /**DAC channel OUT1 config 
    */
  sConfig.DAC_Trigger = DAC_TRIGGER_NONE;
  sConfig.DAC_OutputBuffer = DAC_OUTPUTBUFFER_DISABLE;
  if (HAL_DAC_ConfigChannel(&hdac2, &sConfig, DAC_CHANNEL_1) != HAL_OK)
  {
    _Error_Handler(__FILE__, __LINE__);
  }

}

/* I2C2 init function */
static void MX_I2C2_Init(void)
{

  hi2c2.Instance = I2C2;
  hi2c2.Init.Timing = 0x2000090E;
  hi2c2.Init.OwnAddress1 = 0;
  hi2c2.Init.AddressingMode = I2C_ADDRESSINGMODE_7BIT;
  hi2c2.Init.DualAddressMode = I2C_DUALADDRESS_DISABLE;
  hi2c2.Init.OwnAddress2 = 0;
  hi2c2.Init.OwnAddress2Masks = I2C_OA2_NOMASK;
  hi2c2.Init.GeneralCallMode = I2C_GENERALCALL_DISABLE;
  hi2c2.Init.NoStretchMode = I2C_NOSTRETCH_DISABLE;
  if (HAL_I2C_Init(&hi2c2) != HAL_OK)
  {
    _Error_Handler(__FILE__, __LINE__);
  }

    /**Configure Analogue filter 
    */
  if (HAL_I2CEx_ConfigAnalogFilter(&hi2c2, I2C_ANALOGFILTER_ENABLE) != HAL_OK)
  {
    _Error_Handler(__FILE__, __LINE__);
  }

    /**Configure Digital filter 
    */
  if (HAL_I2CEx_ConfigDigitalFilter(&hi2c2, 0) != HAL_OK)
  {
    _Error_Handler(__FILE__, __LINE__);
  }

}

/* RTC init function */
static void MX_RTC_Init(void)
{

  RTC_TimeTypeDef sTime;
  RTC_DateTypeDef sDate;

    /**Initialize RTC Only 
    */
  hrtc.Instance = RTC;
  hrtc.Init.HourFormat = RTC_HOURFORMAT_24;
  hrtc.Init.AsynchPrediv = 127;
  hrtc.Init.SynchPrediv = 255;
  hrtc.Init.OutPut = RTC_OUTPUT_DISABLE;
  hrtc.Init.OutPutPolarity = RTC_OUTPUT_POLARITY_HIGH;
  hrtc.Init.OutPutType = RTC_OUTPUT_TYPE_OPENDRAIN;
  if (HAL_RTC_Init(&hrtc) != HAL_OK)
  {
    _Error_Handler(__FILE__, __LINE__);
  }

    /**Initialize RTC and set the Time and Date 
    */
  if(HAL_RTCEx_BKUPRead(&hrtc, RTC_BKP_DR0) != 0x32F2){
  sTime.Hours = 0;
  sTime.Minutes = 0;
  sTime.Seconds = 0;
  sTime.DayLightSaving = RTC_DAYLIGHTSAVING_NONE;
  sTime.StoreOperation = RTC_STOREOPERATION_RESET;
  if (HAL_RTC_SetTime(&hrtc, &sTime, RTC_FORMAT_BIN) != HAL_OK)
  {
    _Error_Handler(__FILE__, __LINE__);
  }

  sDate.WeekDay = RTC_WEEKDAY_MONDAY;
  sDate.Month = RTC_MONTH_JANUARY;
  sDate.Date = 1;
  sDate.Year = 0;

  if (HAL_RTC_SetDate(&hrtc, &sDate, RTC_FORMAT_BIN) != HAL_OK)
  {
    _Error_Handler(__FILE__, __LINE__);
  }

    HAL_RTCEx_BKUPWrite(&hrtc,RTC_BKP_DR0,0x32F2);
  }

}

/* SDADC1 init function */
static void MX_SDADC1_Init(void)
{

  SDADC_ConfParamTypeDef ConfParamStruct;

    /**Configure the SDADC low power mode, fast conversion mode,
    slow clock mode and SDADC1 reference voltage 
    */
  hsdadc1.Instance = SDADC1;
  hsdadc1.Init.IdleLowPowerMode = SDADC_LOWPOWER_NONE;
  hsdadc1.Init.FastConversionMode = SDADC_FAST_CONV_DISABLE;
  hsdadc1.Init.SlowClockMode = SDADC_SLOW_CLOCK_DISABLE;
  hsdadc1.Init.ReferenceVoltage = SDADC_VREF_EXT;
  if (HAL_SDADC_Init(&hsdadc1) != HAL_OK)
  {
    _Error_Handler(__FILE__, __LINE__);
  }

    /**Configure The Regular Mode 
    */
  if (HAL_SDADC_SelectRegularTrigger(&hsdadc1, SDADC_SOFTWARE_TRIGGER) != HAL_OK)
  {
    _Error_Handler(__FILE__, __LINE__);
  }

    /**Set parameters for SDADC configuration 0 Register 
    */
  ConfParamStruct.InputMode = SDADC_INPUT_MODE_SE_ZERO_REFERENCE;
  ConfParamStruct.Gain = SDADC_GAIN_1;
  ConfParamStruct.CommonMode = SDADC_COMMON_MODE_VSSA;
  ConfParamStruct.Offset = 0;
  if (HAL_SDADC_PrepareChannelConfig(&hsdadc1, SDADC_CONF_INDEX_0, &ConfParamStruct) != HAL_OK)
  {
    _Error_Handler(__FILE__, __LINE__);
  }

}

/* SDADC3 init function */
static void MX_SDADC3_Init(void)
{

  SDADC_ConfParamTypeDef ConfParamStruct;

    /**Configure the SDADC low power mode, fast conversion mode,
    slow clock mode and SDADC1 reference voltage 
    */
  hsdadc3.Instance = SDADC3;
  hsdadc3.Init.IdleLowPowerMode = SDADC_LOWPOWER_NONE;
  hsdadc3.Init.FastConversionMode = SDADC_FAST_CONV_DISABLE;
  hsdadc3.Init.SlowClockMode = SDADC_SLOW_CLOCK_DISABLE;
  hsdadc3.Init.ReferenceVoltage = SDADC_VREF_EXT;
  if (HAL_SDADC_Init(&hsdadc3) != HAL_OK)
  {
    _Error_Handler(__FILE__, __LINE__);
  }

    /**Configure The Regular Mode 
    */
  if (HAL_SDADC_SelectRegularTrigger(&hsdadc3, SDADC_SOFTWARE_TRIGGER) != HAL_OK)
  {
    _Error_Handler(__FILE__, __LINE__);
  }

    /**Set parameters for SDADC configuration 1 Register 
    */
  ConfParamStruct.InputMode = SDADC_INPUT_MODE_DIFF;
  ConfParamStruct.Gain = SDADC_GAIN_1;
  ConfParamStruct.CommonMode = SDADC_COMMON_MODE_VSSA;
  ConfParamStruct.Offset = 0;
  if (HAL_SDADC_PrepareChannelConfig(&hsdadc3, SDADC_CONF_INDEX_1, &ConfParamStruct) != HAL_OK)
  {
    _Error_Handler(__FILE__, __LINE__);
  }

}

/* TIM3 init function */
static void MX_TIM3_Init(void)
{

  TIM_ClockConfigTypeDef sClockSourceConfig;
  TIM_MasterConfigTypeDef sMasterConfig;
  TIM_OC_InitTypeDef sConfigOC;

  htim3.Instance = TIM3;
  htim3.Init.Prescaler = 0;
  htim3.Init.CounterMode = TIM_COUNTERMODE_UP;
  htim3.Init.Period = 0;
  htim3.Init.ClockDivision = TIM_CLOCKDIVISION_DIV1;
  htim3.Init.AutoReloadPreload = TIM_AUTORELOAD_PRELOAD_ENABLE;
  if (HAL_TIM_Base_Init(&htim3) != HAL_OK)
  {
    _Error_Handler(__FILE__, __LINE__);
  }

  sClockSourceConfig.ClockSource = TIM_CLOCKSOURCE_INTERNAL;
  if (HAL_TIM_ConfigClockSource(&htim3, &sClockSourceConfig) != HAL_OK)
  {
    _Error_Handler(__FILE__, __LINE__);
  }

  if (HAL_TIM_PWM_Init(&htim3) != HAL_OK)
  {
    _Error_Handler(__FILE__, __LINE__);
  }

  sMasterConfig.MasterOutputTrigger = TIM_TRGO_RESET;
  sMasterConfig.MasterSlaveMode = TIM_MASTERSLAVEMODE_DISABLE;
  if (HAL_TIMEx_MasterConfigSynchronization(&htim3, &sMasterConfig) != HAL_OK)
  {
    _Error_Handler(__FILE__, __LINE__);
  }

  sConfigOC.OCMode = TIM_OCMODE_PWM1;
  sConfigOC.Pulse = 0;
  sConfigOC.OCPolarity = TIM_OCPOLARITY_HIGH;
  sConfigOC.OCFastMode = TIM_OCFAST_DISABLE;
  if (HAL_TIM_PWM_ConfigChannel(&htim3, &sConfigOC, TIM_CHANNEL_2) != HAL_OK)
  {
    _Error_Handler(__FILE__, __LINE__);
  }

  HAL_TIM_MspPostInit(&htim3);

}

/* TIM4 init function */
static void MX_TIM4_Init(void)
{

  TIM_ClockConfigTypeDef sClockSourceConfig;
  TIM_MasterConfigTypeDef sMasterConfig;
  TIM_IC_InitTypeDef sConfigIC;

  htim4.Instance = TIM4;
  htim4.Init.Prescaler = 0;
  htim4.Init.CounterMode = TIM_COUNTERMODE_UP;
  htim4.Init.Period = 0xFFFF;
  htim4.Init.ClockDivision = TIM_CLOCKDIVISION_DIV1;
  htim4.Init.AutoReloadPreload = TIM_AUTORELOAD_PRELOAD_ENABLE;
  if (HAL_TIM_Base_Init(&htim4) != HAL_OK)
  {
    _Error_Handler(__FILE__, __LINE__);
  }

  sClockSourceConfig.ClockSource = TIM_CLOCKSOURCE_INTERNAL;
  if (HAL_TIM_ConfigClockSource(&htim4, &sClockSourceConfig) != HAL_OK)
  {
    _Error_Handler(__FILE__, __LINE__);
  }

  if (HAL_TIM_IC_Init(&htim4) != HAL_OK)
  {
    _Error_Handler(__FILE__, __LINE__);
  }

  sMasterConfig.MasterOutputTrigger = TIM_TRGO_RESET;
  sMasterConfig.MasterSlaveMode = TIM_MASTERSLAVEMODE_DISABLE;
  if (HAL_TIMEx_MasterConfigSynchronization(&htim4, &sMasterConfig) != HAL_OK)
  {
    _Error_Handler(__FILE__, __LINE__);
  }

  sConfigIC.ICPolarity = TIM_INPUTCHANNELPOLARITY_FALLING;
  sConfigIC.ICSelection = TIM_ICSELECTION_DIRECTTI;
  sConfigIC.ICPrescaler = TIM_ICPSC_DIV1;
  sConfigIC.ICFilter = 0;
  if (HAL_TIM_IC_ConfigChannel(&htim4, &sConfigIC, TIM_CHANNEL_4) != HAL_OK)
  {
    _Error_Handler(__FILE__, __LINE__);
  }

}

/* TIM5 init function */
static void MX_TIM5_Init(void)
{

  TIM_ClockConfigTypeDef sClockSourceConfig;
  TIM_MasterConfigTypeDef sMasterConfig;

  htim5.Instance = TIM5;
  htim5.Init.Prescaler = 0;
  htim5.Init.CounterMode = TIM_COUNTERMODE_UP;
  htim5.Init.Period = 0;
  htim5.Init.ClockDivision = TIM_CLOCKDIVISION_DIV1;
  htim5.Init.AutoReloadPreload = TIM_AUTORELOAD_PRELOAD_ENABLE;
  if (HAL_TIM_Base_Init(&htim5) != HAL_OK)
  {
    _Error_Handler(__FILE__, __LINE__);
  }

  sClockSourceConfig.ClockSource = TIM_CLOCKSOURCE_INTERNAL;
  if (HAL_TIM_ConfigClockSource(&htim5, &sClockSourceConfig) != HAL_OK)
  {
    _Error_Handler(__FILE__, __LINE__);
  }

  sMasterConfig.MasterOutputTrigger = TIM_TRGO_RESET;
  sMasterConfig.MasterSlaveMode = TIM_MASTERSLAVEMODE_DISABLE;
  if (HAL_TIMEx_MasterConfigSynchronization(&htim5, &sMasterConfig) != HAL_OK)
  {
    _Error_Handler(__FILE__, __LINE__);
  }

}

/* TIM19 init function */
static void MX_TIM19_Init(void)
{

  TIM_ClockConfigTypeDef sClockSourceConfig;
  TIM_MasterConfigTypeDef sMasterConfig;
  TIM_OC_InitTypeDef sConfigOC;

  htim19.Instance = TIM19;
  htim19.Init.Prescaler = 720;
  htim19.Init.CounterMode = TIM_COUNTERMODE_UP;
  htim19.Init.Period = 10000;
  htim19.Init.ClockDivision = TIM_CLOCKDIVISION_DIV1;
  htim19.Init.AutoReloadPreload = TIM_AUTORELOAD_PRELOAD_ENABLE;
  if (HAL_TIM_Base_Init(&htim19) != HAL_OK)
  {
    _Error_Handler(__FILE__, __LINE__);
  }

  sClockSourceConfig.ClockSource = TIM_CLOCKSOURCE_INTERNAL;
  if (HAL_TIM_ConfigClockSource(&htim19, &sClockSourceConfig) != HAL_OK)
  {
    _Error_Handler(__FILE__, __LINE__);
  }

  if (HAL_TIM_OC_Init(&htim19) != HAL_OK)
  {
    _Error_Handler(__FILE__, __LINE__);
  }

  sMasterConfig.MasterOutputTrigger = TIM_TRGO_RESET;
  sMasterConfig.MasterSlaveMode = TIM_MASTERSLAVEMODE_DISABLE;
  if (HAL_TIMEx_MasterConfigSynchronization(&htim19, &sMasterConfig) != HAL_OK)
  {
    _Error_Handler(__FILE__, __LINE__);
  }

  sConfigOC.OCMode = TIM_OCMODE_ACTIVE;
  sConfigOC.Pulse = 0;
  sConfigOC.OCPolarity = TIM_OCPOLARITY_HIGH;
  sConfigOC.OCFastMode = TIM_OCFAST_DISABLE;
  if (HAL_TIM_OC_ConfigChannel(&htim19, &sConfigOC, TIM_CHANNEL_4) != HAL_OK)
  {
    _Error_Handler(__FILE__, __LINE__);
  }

}

/* USART2 init function */
static void MX_USART2_UART_Init(void)
{

  huart2.Instance = USART2;
  huart2.Init.BaudRate = 115200;
  huart2.Init.WordLength = UART_WORDLENGTH_8B;
  huart2.Init.StopBits = UART_STOPBITS_1;
  huart2.Init.Parity = UART_PARITY_NONE;
  huart2.Init.Mode = UART_MODE_TX_RX;
  huart2.Init.HwFlowCtl = UART_HWCONTROL_NONE;
  huart2.Init.OverSampling = UART_OVERSAMPLING_16;
  huart2.Init.OneBitSampling = UART_ONE_BIT_SAMPLE_DISABLE;
  huart2.AdvancedInit.AdvFeatureInit = UART_ADVFEATURE_NO_INIT;
  if (HAL_UART_Init(&huart2) != HAL_OK)
  {
    _Error_Handler(__FILE__, __LINE__);
  }

}

/** 
  * Enable DMA controller clock
  */
static void MX_DMA_Init(void) 
{
  /* DMA controller clock enable */
  __HAL_RCC_DMA1_CLK_ENABLE();
  __HAL_RCC_DMA2_CLK_ENABLE();

  /* DMA interrupt init */
  /* DMA1_Channel1_IRQn interrupt configuration */
  HAL_NVIC_SetPriority(DMA1_Channel1_IRQn, 5, 0);
  HAL_NVIC_EnableIRQ(DMA1_Channel1_IRQn);
  /* DMA1_Channel6_IRQn interrupt configuration */
  HAL_NVIC_SetPriority(DMA1_Channel6_IRQn, 5, 0);
  HAL_NVIC_EnableIRQ(DMA1_Channel6_IRQn);
  /* DMA1_Channel7_IRQn interrupt configuration */
  HAL_NVIC_SetPriority(DMA1_Channel7_IRQn, 5, 0);
  HAL_NVIC_EnableIRQ(DMA1_Channel7_IRQn);
  /* DMA2_Channel3_IRQn interrupt configuration */
  HAL_NVIC_SetPriority(DMA2_Channel3_IRQn, 5, 0);
  HAL_NVIC_EnableIRQ(DMA2_Channel3_IRQn);
  /* DMA2_Channel5_IRQn interrupt configuration */
  HAL_NVIC_SetPriority(DMA2_Channel5_IRQn, 5, 0);
  HAL_NVIC_EnableIRQ(DMA2_Channel5_IRQn);

}
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

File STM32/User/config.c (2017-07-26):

#include "board.h"
#include "usb_device.h"
#include "usbd_cdc_if.h"

//#include "stm32f3xx_hal.h"
//#include "cmsis_os.h"
//#include <stdbool.h>
//#include <string.h>
//#include "config.h"

//sys_t sys;
measu_t measu_data;


//core_t core;

config_t cfg;
master_t mcfg;

//	#define FLASH_PAGE_COUNT 256
//		#define FLASH_PAGE_SIZE                 ((uint16_t)0x400)
//		#define CONFIG_SIZE                     (FLASH_PAGE_SIZE * 2)


#ifdef STM32F10X_LD
	#define FLASH_PAGE_COUNT 32
	#define FLASH_PAGE_SIZE                 ((uint16_t)0x400)
	#define CONFIG_SIZE                     (FLASH_PAGE_SIZE * 2)
#endif

#ifdef STM32F10X_MD
	#define FLASH_PAGE_COUNT 128
	#define FLASH_PAGE_SIZE                 ((uint16_t)0x400)
	#define CONFIG_SIZE                     (FLASH_PAGE_SIZE * 2)
#endif

#ifdef STM32F303xC
	#define FLASH_PAGE_COUNT 256
		#define FLASH_PAGE_SIZE                 ((uint16_t)0x400)
		#define CONFIG_SIZE                     (FLASH_PAGE_SIZE * 2)
#endif

#ifdef STM32F373xC
	#define FLASH_PAGE_COUNT 128
//		#define FLASH_PAGE_SIZE                 ((uint16_t)0x800)
		#define CONFIG_SIZE                     (FLASH_PAGE_SIZE * 1)
#endif

#ifdef STM32F373xB
	#define FLASH_PAGE_COUNT 128
		#define FLASH_PAGE_SIZE                 ((uint16_t)0x400)
		#define CONFIG_SIZE                     (FLASH_PAGE_SIZE * 2)
#endif


static const uint8_t EEPROM_CONF_VERSION = EEPROM_VERSION;
static const uint32_t FLASH_WRITE_ADDR = 0x08000000 + (FLASH_PAGE_SIZE * (FLASH_PAGE_COUNT - (CONFIG_SIZE / FLASH_PAGE_SIZE)));



system_t 	sys;
config_t cfg;

//core_t core;
 master_t mcfg;



void config_value_update_check_and_save (void) {
//	static uint32_t befor_time=0, save_interval_time;
//	uint32_t timeNow=millis();
//	static bool save_eeprom_f=false;

//    if ((( (int64_t)timeNow - befor_time-500) < 0 && timeNow >= befor_time) ) {
//			return ;
//		}
//		befor_time = timeNow;
		vTaskDelay(500);
		
		if(sys.system_reboot_flag) {		//reboot flag가 설정 된경우
//				systemReset(false);
				NVIC_SystemReset();
		}
		
		if(sys.eeprom_write_f ) {		//lcd gui에서 config 변경시에는 바로 변경
				sys.eeprom_write_f = false;
				writeEEPROM(1, true); 
		}
		if(sys.bus_to_config_update_f ) {	//통신으로 config 변경시에는 일정 시간 후 변경
				sys.bus_to_config_update_f = false;
//				save_eeprom_f = true;
//				save_interval_time = timeNow;
//				TASK1 -> xTaskGetTickCount() =0;
		}
		/* 저장 플래그후 일정시간 이상 플래그 신호가 없을 경우 기록 실행 */
//    if ((( (int64_t)timeNow - save_interval_time-5000) < 0 && timeNow >= save_interval_time) || save_eeprom_f == false ) {
//			return ;
//		}
//		save_eeprom_f = false;
//		 writeEEPROM(1, true); 
		
//		writeFLASH(Factory_cfg_buff, sizeof(Factory_cfg_t), FLASH_FACTORY_CFG_ADDR);
//		writeFLASH(controler_cfg_buff, sizeof(controler_cfg_t), FLASH_CONTROLER_CFG_ADDR);
	
}



//void system_config_set_init(void) {
//		sys.hw_version = HW_VERSION;
//		sys.fw_version = 	FW_VERSION;
//}



void initEEPROM(void)
{
    // make sure (at compile time) that config struct doesn't overflow allocated flash pages
    ct_assert(sizeof(mcfg) < CONFIG_SIZE);
}


static uint8_t validEEPROM(void)
{
    const master_t *temp = (const master_t *)FLASH_WRITE_ADDR;
    const uint8_t *p;
    uint8_t chk = 0;

    // check version number
    if (EEPROM_CONF_VERSION != temp->version)
        return 0;

    // check size and magic numbers
    if (temp->size != sizeof(master_t) || temp->magic_be != 0xBE || temp->magic_ef != 0xEF)
        return 0;

    // verify integrity of temporary copy
    for (p = (const uint8_t *)temp; p < ((const uint8_t *)temp + sizeof(master_t)); p++)
        chk ^= *p;

    // checksum failed
    if (chk != 0)
        return 0;

    // looks good, let's roll!
    return 1;
}


void readEEPROM(void)
{
    // Sanity check
    if (!validEEPROM()){
//        failureMode(10);
		}

    // Read flash
    memcpy(&mcfg, (char *)FLASH_WRITE_ADDR, sizeof(master_t));
    // Copy current profile
//    if (mcfg.current_profile > 2) // sanity check
//        mcfg.current_profile = 0;
    memcpy(&cfg, &mcfg.profile, sizeof(config_t));
}



void loadAndActivateConfig(void)
{
    readEEPROM();
//    activateConfig();
}
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

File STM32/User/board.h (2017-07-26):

#pragma once

#include "stm32f3xx_hal.h"
#include "cmsis_os.h"
#include <stdbool.h>
#include <string.h>


#define EEPROM_VERSION 1
#define UART1_BAURD 115200


#define DAC_RESOLUTION 	0x0FFF		//12bit
//#define DAC_OUTPUT_MIN_DEFAULT_mV		0
#define DAC_OUTPUT_MAX_DEFAULT_mV		5000


#define SDADC_VREF        2500  /* SDADC external reference is set to 3.3V */
#define TC_VREF		1250
#define DEFAULT_ADC_REF_3_3V_mV     3300    // ADC Ref Voltage
#define MAX_12BIT_ADC_CHANNEL 	2


#define DC_MEAS_Reg_PullUp  115000      //ohm
#define DC_MEAS_Reg_PullDown  10000    //ohm
#define  ADC_TO_VOLTAGE_RATIO		((4095/((((float)DC_MEAS_Reg_PullUp+DC_MEAS_Reg_PullDown)/DC_MEAS_Reg_PullDown)*((float)mcfg.Vref_ADC_mV/1000)))/1000)


#define KELVIN_ADC_GAIN           (uint32_t) 1
#define TC_ADC_GAIN           (uint32_t) 1
#define SDADC_RESOL          (uint32_t) 65535 /* 2e16 - 1 */
#define AD8495_mV_FOR_degC		5
#define AD8495_PULLUP_REG		30000
#define AD8495_PULLDOWN_REG		10000
#define AD8495_VOUT_RATIO			((AD8495_PULLUP_REG+AD8495_PULLDOWN_REG)/AD8495_PULLDOWN_REG)

	
#ifdef RANGE_Pin
//	#define R_100_OHM_RANGE					RANGE_GPIO_Port->BSRR = RANGE_Pin
//	#define R_1K_OHM_RANGE         RANGE_GPIO_Port->BRR = RANGE_Pin
	#define KELVIN_CURRENT_10mA					RANGE_GPIO_Port->BSRR = RANGE_Pin
	#define KELVIN_CURRENT_1mA         RANGE_GPIO_Port->BRR = RANGE_Pin
#else
	#define R_100_RANGE				;
	#define R_1K_RANGE         ;
#endif


//#define USB_DISCONNEC_PORT 	USB_EN_GPIO_Port
//#define USB_DISCONNECT_PIN 		 USB_EN_Pin

//#define USB_DECTETION_ENABLE                  digitalLo(USB_DISCONNEC_PORT, USB_DISCONNECT_PIN)	//fet on
//#define USB_DECTETION_DISABLE                digitalHi(USB_DISCONNEC_PORT, USB_DISCONNECT_PIN)		//fet off
#define USB_DECTETION_DISABLE                  USB_EN_GPIO_Port->BRR = USB_EN_Pin	//npn tr off
#define USB_DECTETION_ENABLE               USB_EN_GPIO_Port->BSRR = USB_EN_Pin		//npn tr on

#ifdef RELAY_Pin
	#define RELAY1_ON					RELAY_GPIO_Port->BSRR = RELAY_Pin
	#define RELAY1_OFF         RELAY_GPIO_Port->BRR = RELAY_Pin
	#define RELAY1_TOGGLE         digitalToggle(RELAY_GPIO_Port,RELAY_Pin)
#endif


#ifdef L1_Pin
	#define L1_ON					L1_GPIO_Port->BSRR = L1_Pin
	#define L1_OFF         L1_GPIO_Port->BRR = L1_Pin
	#define L1_TOGGLE         digitalToggle(L1_GPIO_Port,L1_Pin)
#else
	#define L1_ON				;
	#define L1_OFF         ;
	#define L1_TOGGLE         ;
#endif

#ifdef L2_Pin
	#define L2_ON					L2_GPIO_Port->BSRR = L2_Pin
	#define L2_OFF         L2_GPIO_Port->BRR = L2_Pin
	#define L2_TOGGLE         digitalToggle(L2_GPIO_Port,L2_Pin)
#else
	#define L2_ON				;
	#define L2_OFF         ;
	#define L2_TOGGLE         ;
#endif

#ifdef L3_Pin
	#define L3_ON					L3_GPIO_Port->BSRR = L3_Pin
	#define L3_OFF         L3_GPIO_Port->BRR = L3_Pin
	#define L3_TOGGLE         digitalToggle(L3_GPIO_Port,L3_Pin)
#else
	#define L3_ON				;
	#define L3_OFF         ;
	#define L3_TOGGLE         ;
#endif

#ifdef C_CTL_Pin
	#define C_CTL_HIGH					C_CTL_GPIO_Port->BSRR = C_CTL_Pin
	#define C_CTL_LOW        C_CTL_GPIO_Port->BRR = C_CTL_Pin
	#define C_CTL_TOGGLE         digitalToggle(C_CTL_GPIO_Port,C_CTL_Pin)
#else
	#define C_CTL_HIGH				;
	#define C_CTL_LOW        ;
	#define C_CTL_TOGGLE         ;
#endif

#define RED_DI_CH1		((DI_CH1_GPIO_Port->IDR & DI_CH1_Pin) != (uint32_t)GPIO_PIN_RESET)
#define RED_DI_CH2		((DI_CH2_GPIO_Port->IDR & DI_CH2_Pin) != (uint32_t)GPIO_PIN_RESET)
#define RED_DI_CH3		((DI_CH3_GPIO_Port->IDR & DI_CH3_Pin) != (uint32_t)GPIO_PIN_RESET)

#define READ_DI_PORT		((RED_DI_CH1 | (RED_DI_CH2<<1) | (RED_DI_CH1<<2))&0x07)

#include "drv_system.h"
#include "adc.h"
#include "lc_meter.h"
//#include "drv_uart.h"
//#include "drv_serial.h"
//#include "serial.h"
#include "uart_dma.h"
#include "serial.h"

#include "vcp.h"
#include "can.h"
#include "can_queue.h"
#include "cli.h"
#include "function.h"
#include "dac.h"
#include "config.h"
#include "Digital_control.h"
#include "rtc.h"

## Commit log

2017-07-23 stm32 beta 0.1 source
2017-07-23 RTC update error complit
    [adc.c, cli.c, config.c]
2017-07-24 SDADC&ADC Frequency Change
2017-07-25 Kelvin Zero Calibration modity
2017-07-25 Kelvin Zero Calibration patch
2017-07-26 Kelvin zeor calibraton
2023-07-31 pcb upload
    [Lattepanda_shild_v1.2.brd, Lattepanda_shild_v1.2.sch, Lattepanda_shild_v1.3.brd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]

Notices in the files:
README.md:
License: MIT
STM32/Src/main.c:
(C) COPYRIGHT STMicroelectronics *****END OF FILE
